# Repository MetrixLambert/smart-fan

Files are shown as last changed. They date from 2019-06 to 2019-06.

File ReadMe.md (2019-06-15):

# ReadMe

This repo contains all files used in my project **pulse** and **smart fan**

对各个文件夹的说明如下：

| folder | folder function |
| --- | --- |
| **0-report** | 两篇论文和作业说明 |
| **1-sim** | 所有的原理图和仿真文件 |
| **2-experiment** | **smart fan** 最终视频 |
| **3-code** | **smart fan** 使用代码 |
| **4-datasheet**  | 所使用芯片的 datasheet |
| **5-PCB** | 最终绘制的PCB文件 |

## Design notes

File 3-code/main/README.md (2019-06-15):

# ReadMe

this is the main program for smart fan 

first need to load LiquidCrystal_I2C module in Arduino 

if not use vscode like me , you can delete "./vscode" folder 

-- from lgr (Ethan)

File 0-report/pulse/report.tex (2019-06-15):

\documentclass{article}
 
\usepackage[margin=1in]{geometry}
\usepackage[strict]{changepage}
\usepackage{float}
\usepackage{fancyhdr}
\usepackage{mhchem}
\usepackage{siunitx}
\usepackage{wrapfig, booktabs}
\usepackage{enumitem}
\usepackage{ctex}
\usepackage{graphicx}
\usepackage{amsmath}
\usepackage{amssymb}
\usepackage{subfigure}
\usepackage{multirow}
\usepackage{multicol}
\usepackage{wrapfig}
\usepackage{indentfirst}
\usepackage[utf8]{inputenc}
\usepackage{geometry}
\usepackage{setspace}   %set space between lines
\usepackage{graphicx} %insert figure 
\usepackage{float} %设置图片浮动位置的宏包
\usepackage{subfigure} %插入多图时用子图显示的宏包
\usepackage{listings}   %插入代码的宏包
\usepackage{xcolor} % to define color 
\usepackage{verbatim}   %for comment 
\usepackage[breaklinks,colorlinks,linkcolor=black,citecolor=black,urlcolor=black]{hyperref} %for bookmark 

\setlength{\parindent}{2em}

\definecolor{mygray}{rgb}{0.5,0.5,0.5}  %totally used in code display
\definecolor{mygreen}{rgb}{0,0.6,0}

\lstset{                %代码显示格式设置
    numbers=left,                                   
    % where to put the line-numbers; possible values are (none, left, right)
    numberstyle=  \color{mygray}, 
    % the style that is used for the line-numbers
    keywordstyle= \color{ blue!70},
    basicstyle=\footnotesize,        
    % the size of the fonts that are used for the code
    commentstyle=\color{mygreen},    
    % comment style
    frame=single,	                   
    % adds a frame around the code, you can use frame=shadowboxs
    % with a rulesepcolor= \color{ red!20!green!20!blue!20} ,
    escapeinside=``, % 英文分号中可写入中文
    xleftmargin=4em,xrightmargin=2em, aboveskip=1em,
    framexleftmargin=2em
} 

\begin{document}

\begin{spacing}{1.5}

    %title  page 
    \thispagestyle{empty}
    \begin{center}
~\\[6cm]\rule{\linewidth}{0.5mm} \\[6mm]
{\Large 综合论文  \\  \textbf{{\LARGE 心率传感电路}}  \\[6mm]}
\rule{\linewidth}{0.5mm} \\[2cm]
{\Large 姓 名: 吕光冉}\\[.3cm]
{\Large 班 级:   自73 }\\[.3cm]
{\Large 学 号:  2017011574}\\[.3cm]
{\Large 日 期：\today }\\[.3cm]
    \end{center}

    \clearpage
    \phantom{s}

    %if need to make table of contents in pdf, below command is okay
\tableofcontents
\newpage

    \subsection{摘要}

    本文介绍了一个基于光电测量法的心率测量电路的设计与实现。
    本电路设计以MK986脉搏心率传感器检测所得波形为输入信号，
    经过运放滤波和信号放大后，通过一个施密特比较器输出处理后的脉搏信号。
    同时，为了增强电路的可靠性，在面包板上搭建电路并验证工作状态无误后，
    我最终绘制了一块PCB板。在实验检测后。成功得到了比较理想的，符合数字
    电平的脉搏信号。

    \textbf{关键词} ：心率测量电路，光电测量法，模拟电路设计

\section{引言——小米手环心率测量电路}

   我所选择的第一个综合论文题目为心率测量电路的设计与制作。

   之所以会选择这个题目，起源是我平时的一个小发现。
   有一次我在没有佩戴小米手环3的情况下，开启了其心率测量功能。结果我惊奇的发现，
   这时的小米手环测出了一个70多的数值。而当我再一次启动手环的测量功能后，
   我发现它竟然测出了180多的数值！
   
   对于我观察到的现象，一方面，我认为作为一款已经迈入市场的消费级电子产品，
   小米手环不应该在没人佩戴的前提下仍然能够测量到脉搏，这在我看来属于是产品设计缺陷。
   其次我认为，在所测量环境基本没有什么变化的时候，小米手环前后两次测量不应该有这么大
   差距。对这两个问题的好奇促使我去研究智能手环中心率测量电路的基本工作原理。
    
   经过调查发现，现在市面上存在的心率测量电路中，
   常见的测量原理有两种，一种是心动电流测量法，还有一种是光电透射（反射）测量法。

   第一种是心动电流测量法，需要使用到无线心率胸带。人体每次心脏跳动时，都会在胸口产生微弱的心动电流，
   而利用带有电极的无线心率胸带，就可以采集分析这样的电流，来对心率进行计数。
   这种测量方法的优点是测量十分精确，并且可以在运动过程中持续测量。但缺点在于其佩戴方式
   比较特殊，所以并不适用于普通消费者，而更适用于一些运动员。

   第二种是光电透射（或反射）测量法，这种测量方法也是智能手环测量心率的基本原理。
   光电透射测量法主要是利用了血液对光的吸收作用。由于在人体中，非血液成分对于光的吸
   收量基本是恒定的，而在血液中，静脉血的吸收波动相比于动脉血的吸收波动又十分微弱，可以忽略不计。
   所以，可以在恒定波长的光源照射下，通过监测“光的吸收率”这一模拟量的变化，并经过一定的滤波和计算后，
   就可以得到人体动脉血的跳动波形，从而获得心率跳动波形。

    其中，基于光电测量法的光电脉搏传感器通常又分成利用透射式和反射式两种。透射式的传感器
    其发射光源和光敏接收器件位于人体两侧，检测的是透射光光强变化，
    而反射式的传感器其光源和光敏器件位于同一侧，接收的是血液漫射和反射的光。
    由于智能手环本身的佩戴方式，其使用的是反射式的传感器。

   而本设计的设计目的为设计一个基于反射式光电透射原理的心率测量电路，最终要输出一个满足数字电平的
   脉搏信号，使得输出波形可以被后续 MCU 电路测量并进行数字处理。

\section{实现方案}

    我的心率测量电路设计方案如图\ref{fig:design_flow}所示：
    \begin{figure}[H]
        \centering
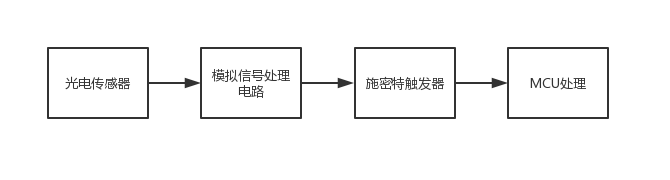
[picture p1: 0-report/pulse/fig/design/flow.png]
        
        \caption{整体设计方案}
        \label{fig:design_flow}
    \end{figure}
    
    在本设计中，光电传感器负责将血液跳动的光信号转化为微弱的电信号，然后经过模拟信号处理电路进行信号放大，噪声抑制以后，
    由施密特触发电路将模拟信号转化为可以由MCU处理的数字信号。

\section{电路原理分析}

    经过测量得知，第一级光电测量电路输出信号大致为一个有直流偏移的，变化幅值大致在100mV左右的脉搏波形。
    其中，直流电压会随着测量时间和接触的皮肤位置不同而变化，而脉搏波形的变化幅值也会因为传感器与皮肤接触的位置不同
    而变化。同时，传感器的输出电阻很小。    

    根据第一级光电传感器输出波形的以上特点，我设计的模拟信号处理电路原理图如图\ref{fig:design1}所示：

    \begin{figure}[H]
        \centering
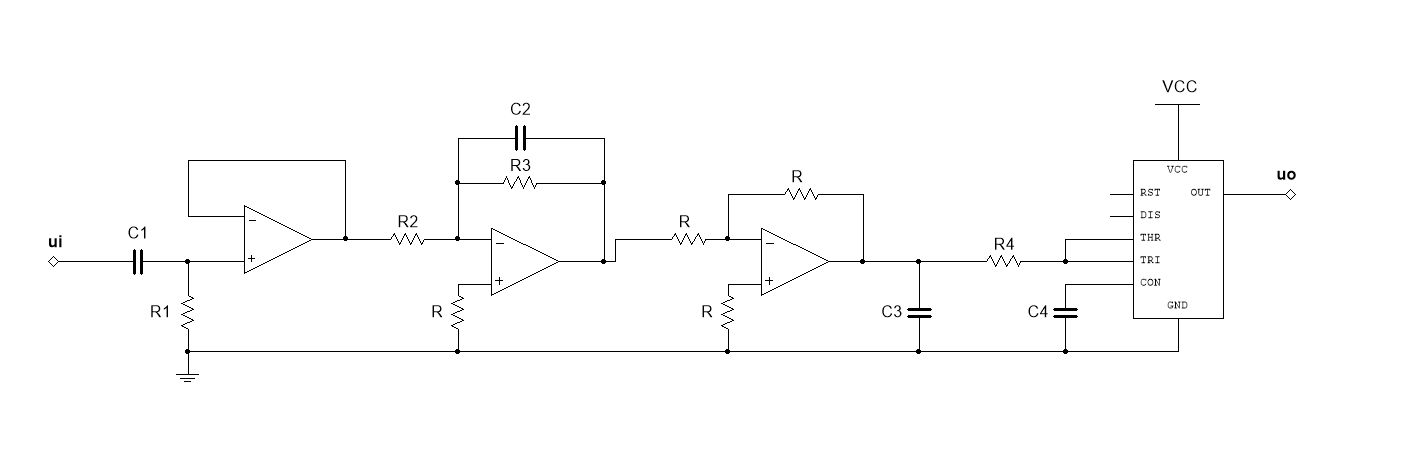
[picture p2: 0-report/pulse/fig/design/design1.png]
        
        \caption{模拟信号处理电路}
        \label{fig:design1}
    \end{figure}

    其中，第一级电路能隔离输入波形中的直流分量，并增大电路的输入电阻至$R_1$，
    第二级电路是一个微分器（相当于一个高通滤波器），并能够进行信号放大并进一步滤去低频噪声，
    第三级电路为低通RC电路和反相器，可以滤去输出级的高频噪声并将波形反向，
    最后一级电路为施密特触发器，可以将放大后的脉搏信号转变符合数字信号电平要求的脉搏信号。

    其中，对于中频段信号，模拟信号处理电路的输入输出电平之间的数学关系式为：
    \begin{equation}
        u_o = - \frac{R_3}{R_2} u_i
    \end{equation}

    通过表达式可知，在调试电路时，可以通过改变$\frac{R_3}{R_2}$ 来调整电路的放大倍数。

    而该电路的截止频率分别为：
    \begin{equation}
        \begin{cases}
            f_l = \frac{1}{2 \pi R_1 C_1}\\
            f_h \approx min \{ \frac{1}{2 \pi R_3 C_2}, \frac{1}{2 \pi R_1 C_1} \}
        \end{cases}
    \end{equation}

    所以可以通过调整 R1,C1,R3等参数来调整电路的幅频特性。

\section{整体电路仿真结果}

    我使用的仿真电路如图\ref{fig:sim1}所示。

    \begin{figure}[H]
        \centering
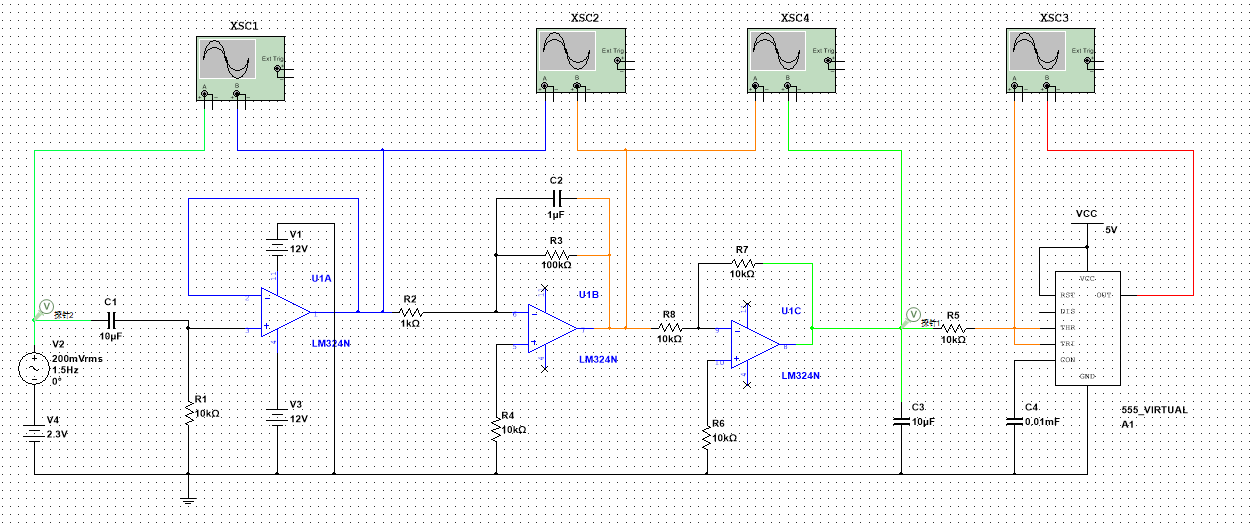
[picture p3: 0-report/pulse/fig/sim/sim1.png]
        
        \caption{心率测量电路仿真电路图}
        \label{fig:sim1}
    \end{figure}

    这里我用了一个直流电源和交流电源的叠加来模拟实际传感器输入信号。

    第一级电路的输入输出波形如图\ref{fig:sim1_result1}所示：
    \begin{figure}[H]
        \centering
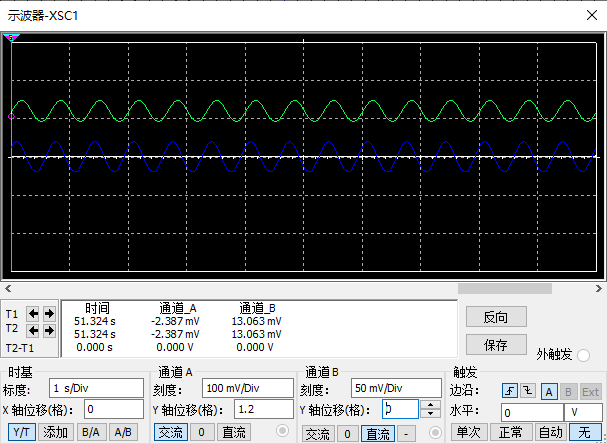
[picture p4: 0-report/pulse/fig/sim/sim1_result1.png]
        
        \caption{第一级电路传输特性}
        \label{fig:sim1_result1}
    \end{figure}
    
    从波形中可以看出，尽管有一定的相移，但是第一级电路已经成功滤去直流分量。

    第二级电路的电压传输特性如图\ref{fig:sim1_result2}所示：
    \begin{figure}[H]
        \centering
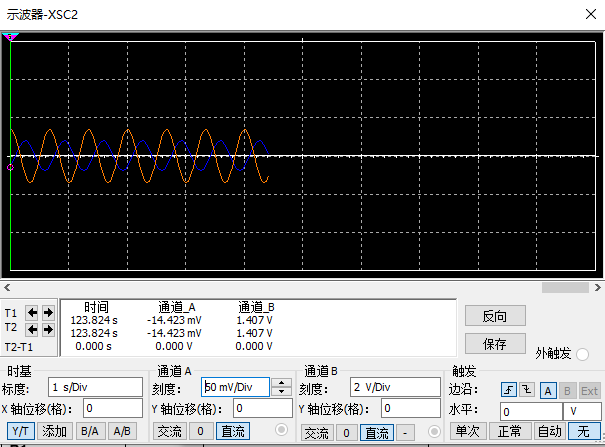
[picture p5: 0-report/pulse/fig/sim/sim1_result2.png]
        
        \caption{第二级电路传输特性}
        \label{fig:sim1_result2}
    \end{figure}
    
    此时，交流信号已经被成功放大。

    在经过低通滤波电路以后，施密特触发器的输入输出波形如图\ref{fig:sim1_result3}所示：
    \begin{figure}[H]
        \centering
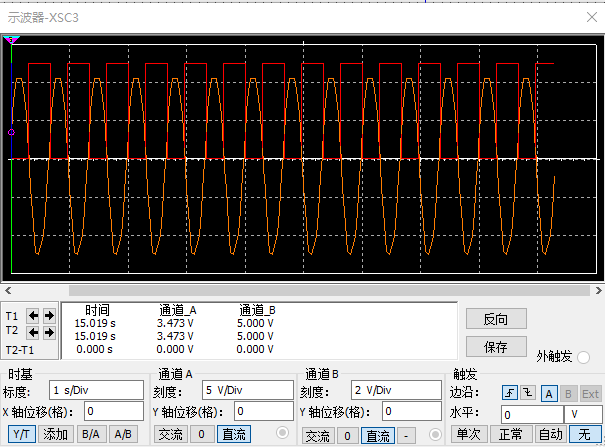
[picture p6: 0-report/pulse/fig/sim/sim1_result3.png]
        
        \caption{施密特电路输入输出波形}
        \label{fig:sim1_result3}
    \end{figure}
    
    可见，此时电路已经能够输出可以被MCU识别的数字信号。

    而对于模拟信号处理电路的幅频特性，仿真结果如图\ref{fig:sim1_result4}所示：
    \begin{figure}[H]
        \centering
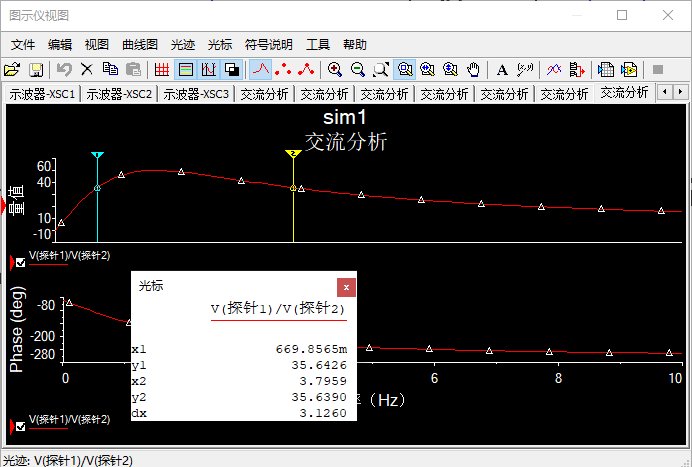
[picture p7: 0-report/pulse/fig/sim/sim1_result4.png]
        
        \caption{电路幅频特性}
        \label{fig:sim1_result4}
    \end{figure}

    可见，电路的低频截止频率为0.6Hz，高频截止频率为3.8Hz。这说明对于一般在1-3Hz的心跳信号，所设计的电路可以有效抑制
    电路高低频噪声并放大有效信号。

\section{电路搭建与实测结果}

    在面包板上搭建完电路并确认电路可以正常工作后，我在李兆基科技大楼绘制并现场制作了一块PCB板。
    但由于李兆基大楼的技术所限，
    我最终制作的仅仅是一块单面PCB板。制作成果如图\ref{fig:PCB1},\ref{fig:PCB2}所示：

    \begin{figure}[H]
        \centering
        
        \caption{PCB板-未焊接}
        \label{fig:PCB1}
    \end{figure}

    \begin{figure}[H]
        \centering
        
        \caption{PCB板-已焊接}
        \label{fig:PCB2}
    \end{figure}
    
    由于在绘制PCB板时，电路封装出现了一些问题，所以最后多使用了一块LM324芯片。

    之后我用魔术胶带将传感器绑在我的手腕上开始测量，如图\ref{fig:pulse1}所示：
    \begin{figure}[H]
        \centering
        
        \caption{传感器绑定方式}
        \label{fig:pulse1}
    \end{figure}
    
    此时，传感器输出波形如图\ref{fig:result1}所示：
    \begin{figure}[H]
        \centering
        
        \caption{传感器输出波形}
        \label{fig:result1}
    \end{figure}

    可见，此时传感器的输出波形中，存在一个2V以上的直流量。而有效的脉搏信号幅值大约有300mV，并且信号中存在
    高频噪声和中频（与脉搏信号频率相近的）噪声。
    
    第一级电路输出波形如图\ref{fig:result2}所示：
    \begin{figure}[H]
        \centering
        
        \caption{第一级电路输出波形}
        \label{fig:result2}
    \end{figure}

    从输出波形可以看出，此时第一级电路已经成功滤去输入信号的直流分量。
    但同时，有效信号的幅值也被减少至200mV左右。

    第二级电路输出波形如图\ref{fig:result3}所示：
    \begin{figure}[H]
        \centering
        
        \caption{第二级电路输出波形}
        \label{fig:result3}
    \end{figure}

    我在实际电路焊接时，我选择使用了一个100k可调电阻来代替仿真电路中的
    $R_3$ 电阻，这样就可以根据输入信号幅值的不同来手动调整电路放大倍数。
    
    如图\ref{fig:result3}所示的输出波形为调整放大倍数后的波形，
    可以看出，此时电路中与脉搏信号频率相近的干扰信号幅值不到1V，在反向后是无法触发施密特触发器的。
    这样一来就可以通过施密特触发器来过滤掉与脉搏信号频率相近的噪声。
    
    同时也可以观察到，在未进行高次噪声滤波前，电路中还是存在很强的高次噪声的。
    这样的噪声可以被后一级低通滤波器和施密特触发器抑制。但这也说明在下一版改进电路中，
    应该在前几级引入低通滤波器来提前抑制高频噪声。
    
    最后级电路输出波形如图\ref{fig:result4}所示：
    \begin{figure}[H]
        \centering
        
        \caption{第三级电路输出波形}
        \label{fig:result4}
    \end{figure}

    可以看出，这时电路已经获得了十分理想的，满足数字电平的脉搏波形。
    （这里的波形在第一次测量时忘记保存，图\ref{fig:result4}为后来补测的结果）。    

\section{实验中电路出现的问题以及原因分析}

    相对于我的第二个项目“智能风扇”，这个项目要简单许多。在制作过程中，我遇到的主要问题包括以下几点：

    \begin{enumerate}
        \item 忽略输出信号正负极性的问题
        
        为了在最后一级仅仅检测正极性信号，我才在最后一级选用了由555构成的施密特触发电路（不需要引入额外的参考电压），而不是
        使用在模电实验中我们通常使用的稳压管滞回比较器（需要引入额外的参考电压才能仅仅检测正电压）。 

        但是在第一次在面包板上搭建电路时，我忽略了第二级电路输出有反向的效果，这导致了原本想要检测的最为明显的
        正脉搏信号变成了负信号，无法被施密特触发器识别。

        这个问题在多引入了一个反相器后，得到了完美的解决。这也提醒我在电路设计时应该关注信号的极性问题。

        \item PCB绘制没有引出测试点
        
        由于是自己初次绘制PCB，没有足够的PCB绘制经验，所以在最终的电路中，PCB上引出的引脚
        只有各类电源和输入输出信号的引脚。
        这导致了在测试PCB电路工作状态时，由于焊接的元件引脚和示波器探头接触面积过小，
        探头上检测到的信号十分不稳定。
        
        所以说在PCB绘制时，应该事先考虑到测试的需要，在PCB板上引出合适的测试点以方便测试。

        \item 电源种类过多

        和我的第二个项目“智能风扇”相同的是，这个电路同样存在电源种类过多的问题。而电源种类过多一方面会增加电源管理模块
        设计的复杂度，另一方面会增大电路功耗，对于一款消费级电子产品是很不合适的。

        而根据所设计电路的实际工作状态，由于所处理的信号为变化的信号，所以电路是存在被改为单电源电路的可能性的。
        
        我初步设计的单电源脉搏检测电路如图\ref{fig:design2}所示：

        \begin{figure}[H]
            \centering
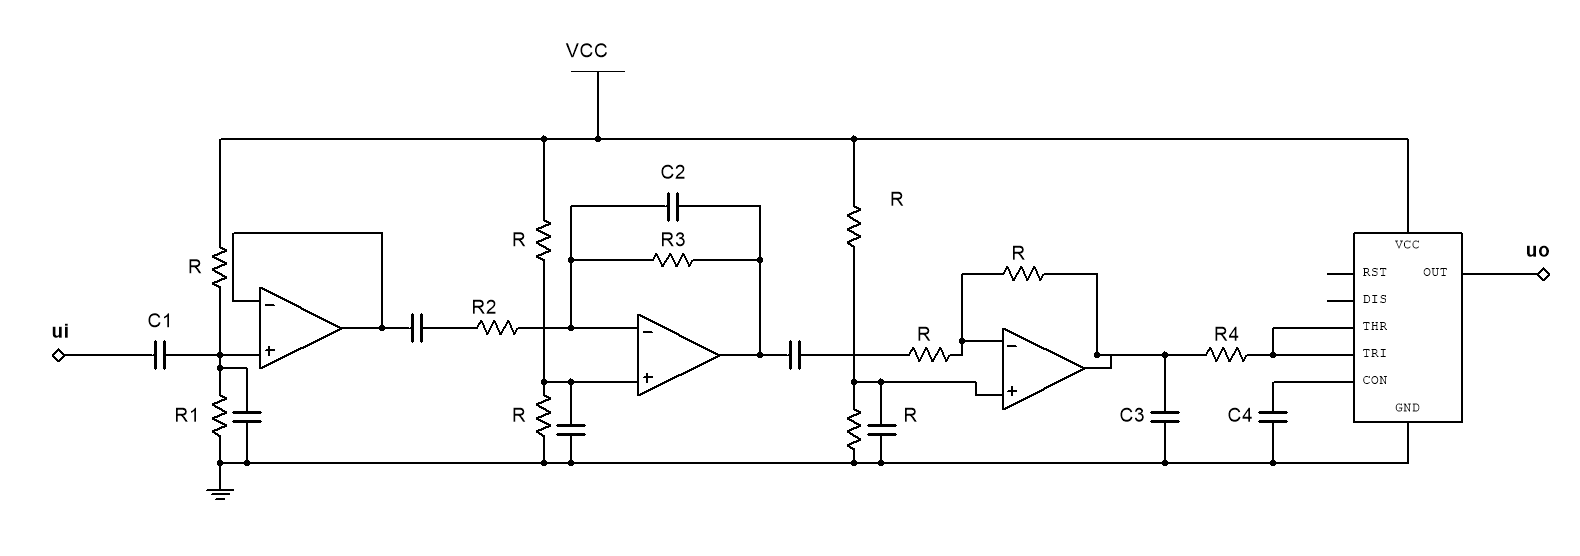
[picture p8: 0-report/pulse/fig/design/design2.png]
            
            \caption{第二版心率测量电路}
            \label{fig:design2}
        \end{figure}
        
        该设计中所有的LM324所接正电压为5V，负电压为0V。其中：
        \begin{enumerate}
            \item $R$ 和 $R_1$负责给运放提供2.5V的参考电位。
            \item $R_1$ 和 $C_1$ 构成高通滤波器，负责隔离电平直流量
            \item 第一级运放为跟随器，负责增大电路的输入电阻
            \item 跟随器后的电容起到进一步隔离直流分量的作用。
            \item R2,R3,C2和第二个运放构成反向微分器（相当于高通滤波器），同时起到放大信号的作用
            \item 第二级运放仍然设置其正极参考电位为2.5V
            \item 第三级运放为一个反相器，其基准电平仍然为2.5V
            \item R4,C3构成低通滤波器，负责过滤高频噪声。
            \item 最后一级由555构成施密特触发器，负责转化波形脉搏波形为数字信号波形。
        \end{enumerate}

        但是由于时间关系，我并没能完成这一版电路的仿真、实验和PCB绘制。这也是本项目的一个遗憾。

    \end{enumerate}

\section{项目的改进方向}

    项目的主要改进方向包括如下几点：

    \begin{enumerate}
        \item 提升传感器的稳定性。在实验时我发现，现在使用的脉搏测量模块工作状态并不完全稳定，其输出会因传感器所接触的皮肤位置不同
        而产生明显变化，
        以致于略微移动一下传感器的位置，就会出现脉搏信号检测不到的问题。
        所以在后续电路改进时，应该首先考虑更换传感器来提升电路工作的稳定性。

        \item 减少电源数量。在最终搭建的电路中，所使用的电源种类过多，包括有正负12V，正5V三种电源。一方面，种类过多给
        电路的搭建和调试带来很大的不便，另一方面，如果该心率传感电路要被融入到消费类电子产品中，减少电源数量可以
        有效的降低因电平转换而消耗的功率，从而提升便携式电子设备的电路工作时间。

        \item 在前几级电路中引入一定的低通滤波器以滤出高频噪声。在实际测量过程中，我发现电路中存在很多的高频噪声，这
        一点在第一版电路设计的时候是没有考虑到的。

    \end{enumerate}

\end{spacing}
\end{document}

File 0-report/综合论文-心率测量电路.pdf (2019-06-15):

## 综合论文

# 心率传感电路

## 姓名: 吕光冉

## 班级: 自 73

学号: 2017011574

## 日期：2019 年 6 月 15 日

目录

1 引言——小米手环心率测量电路 | 3
2 实现方案 | 4
3 电路原理分析 | 4
4 整体电路仿真结果 | 5
5 电路搭建与实测结果 | 6
6 实验中电路出现的问题以及原因分析 | 10
7 项目的改进方向 | 11

### 0.1 摘要

本文介绍了一个基于光电测量法的心率测量电路的设计与实现。本电路设计以 MK986 脉搏心率传

感器检测所得波形为输入信号，经过运放滤波和信号放大后，通过一个施密特比较器输出处理后的脉搏

信号。同时，为了增强电路的可靠性，在面包板上搭建电路并验证工作状态无误后，我最终绘制了一块

PCB 板。在实验检测后。成功得到了比较理想的，符合数字电平的脉搏信号。

关键词：心率测量电路，光电测量法，模拟电路设计

## 1 引言——小米手环心率测量电路

我所选择的第一个综合论文题目为心率测量电路的设计与制作。

之所以会选择这个题目，起源是我平时的一个小发现。有一次我在没有佩戴小米手环 3 的情况下，

开启了其心率测量功能。结果我惊奇的发现，这时的小米手环测出了一个 70 多的数值。而当我再一次

启动手环的测量功能后，我发现它竟然测出了 180 多的数值！

对于我观察到的现象，一方面，我认为作为一款已经迈入市场的消费级电子产品，小米手环不应该

在没人佩戴的前提下仍然能够测量到脉搏，这在我看来属于是产品设计缺陷。其次我认为，在所测量环

境基本没有什么变化的时候，小米手环前后两次测量不应该有这么大差距。对这两个问题的好奇促使

我去研究智能手环中心率测量电路的基本工作原理。

经过调查发现，现在市面上存在的心率测量电路中，常见的测量原理有两种，一种是心动电流测量

法，还有一种是光电透射（反射）测量法。

第一种是心动电流测量法，需要使用到无线心率胸带。人体每次心脏跳动时，都会在胸口产生微弱

的心动电流，而利用带有电极的无线心率胸带，就可以采集分析这样的电流，来对心率进行计数。这种

测量方法的优点是测量十分精确，并且可以在运动过程中持续测量。但缺点在于其佩戴方式比较特殊，

所以并不适用于普通消费者，而更适用于一些运动员。

第二种是光电透射（或反射）测量法，这种测量方法也是智能手环测量心率的基本原理。光电透射

测量法主要是利用了血液对光的吸收作用。由于在人体中，非血液成分对于光的吸收量基本是恒定的，

而在血液中，静脉血的吸收波动相比于动脉血的吸收波动又十分微弱，可以忽略不计。所以，可以在恒

定波长的光源照射下，通过监测“光的吸收率”这一模拟量的变化，并经过一定的滤波和计算后，就可

以得到人体动脉血的跳动波形，从而获得心率跳动波形。

其中，基于光电测量法的光电脉搏传感器通常又分成利用透射式和反射式两种。透射式的传感器其

发射光源和光敏接收器件位于人体两侧，检测的是透射光光强变化，而反射式的传感器其光源和光敏器

件位于同一侧，接收的是血液漫射和反射的光。由于智能手环本身的佩戴方式，其使用的是反射式的传

感器。

而本设计的设计目的为设计一个基于反射式光电透射原理的心率测量电路，最终要输出一个满足

数字电平的脉搏信号，使得输出波形可以被后续 MCU 电路测量并进行数字处理。

## 2 实现方案

我的心率测量电路设计方案如图1所示：

图 1: 整体设计方案

在本设计中，光电传感器负责将血液跳动的光信号转化为微弱的电信号，然后经过模拟信号处理电

路进行信号放大，噪声抑制以后，由施密特触发电路将模拟信号转化为可以由 MCU 处理的数字信号。

## 3 电路原理分析

经过测量得知，第一级光电测量电路输出信号大致为一个有直流偏移的，变化幅值大致在 100mV

左右的脉搏波形。其中，直流电压会随着测量时间和接触的皮肤位置不同而变化，而脉搏波形的变化幅

值也会因为传感器与皮肤接触的位置不同而变化。同时，传感器的输出电阻很小。

根据第一级光电传感器输出波形的以上特点，我设计的模拟信号处理电路原理图如图2所示：


图 2: 模拟信号处理电路

其中，第一级电路能隔离输入波形中的直流分量，并增大电路的输入电阻至 R1，第二级电路是一

个微分器（相当于一个高通滤波器），并能够进行信号放大并进一步滤去低频噪声，第三级电路为低通

RC 电路和反相器，可以滤去输出级的高频噪声并将波形反向，最后一级电路为施密特触发器，可以将

放大后的脉搏信号转变符合数字信号电平要求的脉搏信号。

其中，对于中频段信号，模拟信号处理电路的输入输出电平之间的数学关系式为：

uo = −

R3
R2
ui | (1)

通过表达式可知，在调试电路时，可以通过改变 R3
R2 来调整电路的放大倍数。

而该电路的截止频率分别为：

fl =

1
2πR1C1
fh ≈ min{

1
2πR3C2

,

1
2πR1C1

}

(2)

所以可以通过调整 R1,C1,R3 等参数来调整电路的幅频特性。

## 4 整体电路仿真结果

我使用的仿真电路如图3所示。


图 3: 心率测量电路仿真电路图

这里我用了一个直流电源和交流电源的叠加来模拟实际传感器输入信号。

第一级电路的输入输出波形如图4所示：

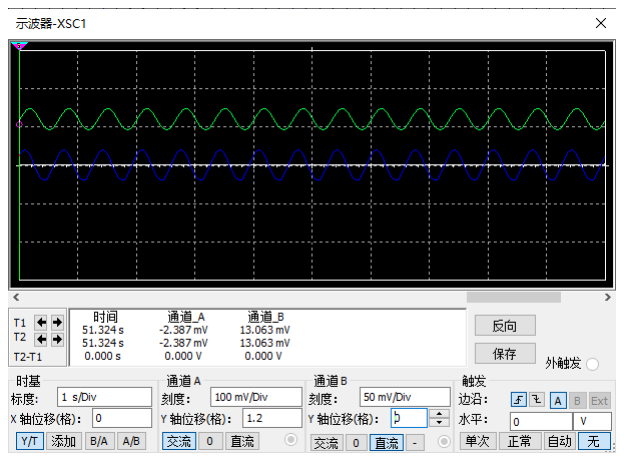
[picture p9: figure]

图 4: 第一级电路传输特性

从波形中可以看出，尽管有一定的相移，但是第一级电路已经成功滤去直流分量。

第二级电路的电压传输特性如图5所示：


图 5: 第二级电路传输特性

此时，交流信号已经被成功放大。

在经过低通滤波电路以后，施密特触发器的输入输出波形如图6所示：


图 6: 施密特电路输入输出波形

可见，此时电路已经能够输出可以被 MCU 识别的数字信号。

而对于模拟信号处理电路的幅频特性，仿真结果如图7所示：

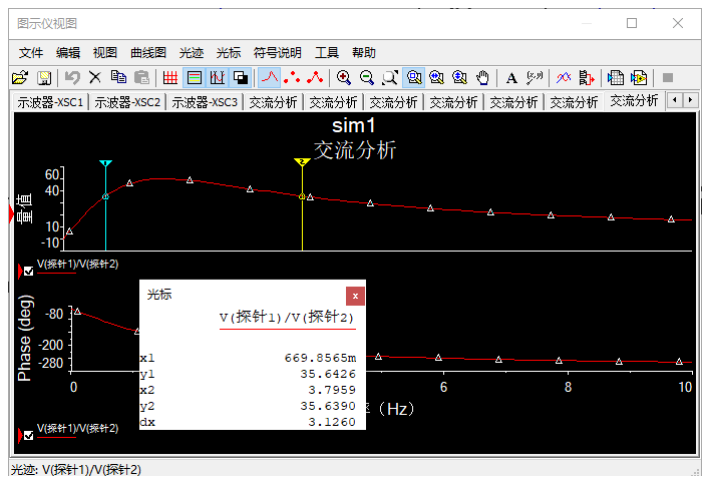
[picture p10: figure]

图 7: 电路幅频特性

可见，电路的低频截止频率为 0.6Hz，高频截止频率为 3.8Hz。这说明对于一般在 1-3Hz 的心跳信

号，所设计的电路可以有效抑制电路高低频噪声并放大有效信号。

## 5 电路搭建与实测结果

在面包板上搭建完电路并确认电路可以正常工作后，我在李兆基科技大楼绘制并现场制作了一块

PCB 板。但由于李兆基大楼的技术所限，我最终制作的仅仅是一块单面 PCB 板。制作成果如图8,9所

示：

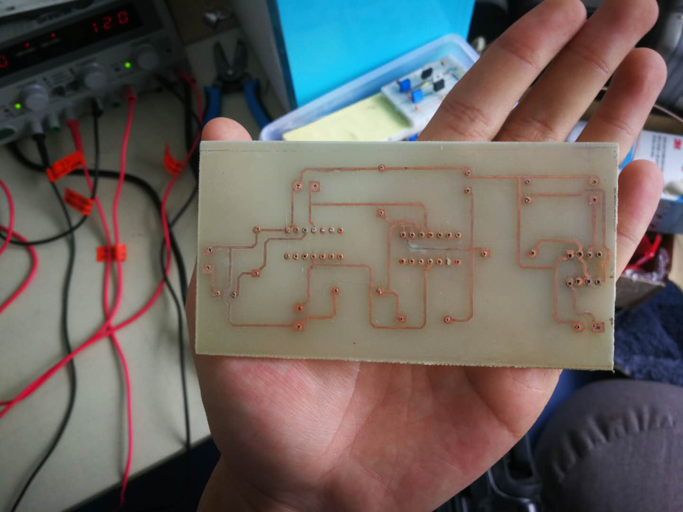
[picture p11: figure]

图 8: PCB 板-未焊接

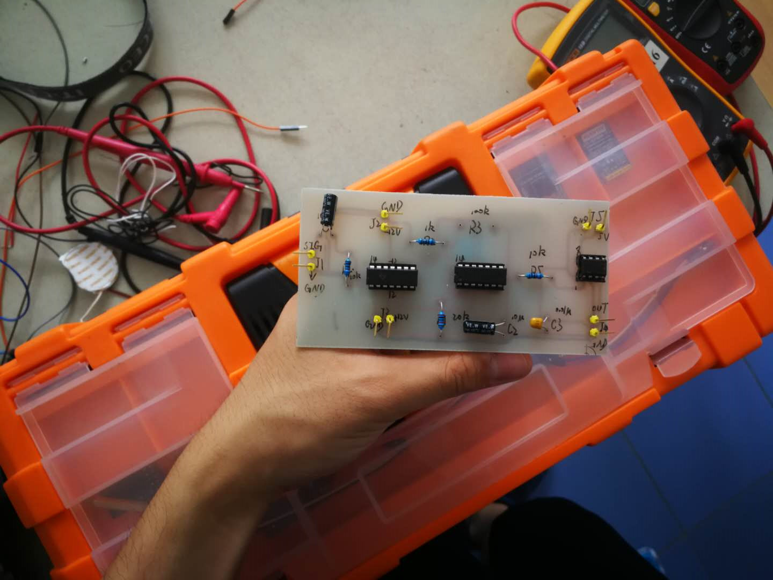
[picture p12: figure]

图 9: PCB 板-已焊接

由于在绘制 PCB 板时，电路封装出现了一些问题，所以最后多使用了一块 LM324 芯片。

之后我用魔术胶带将传感器绑在我的手腕上开始测量，如图10所示：

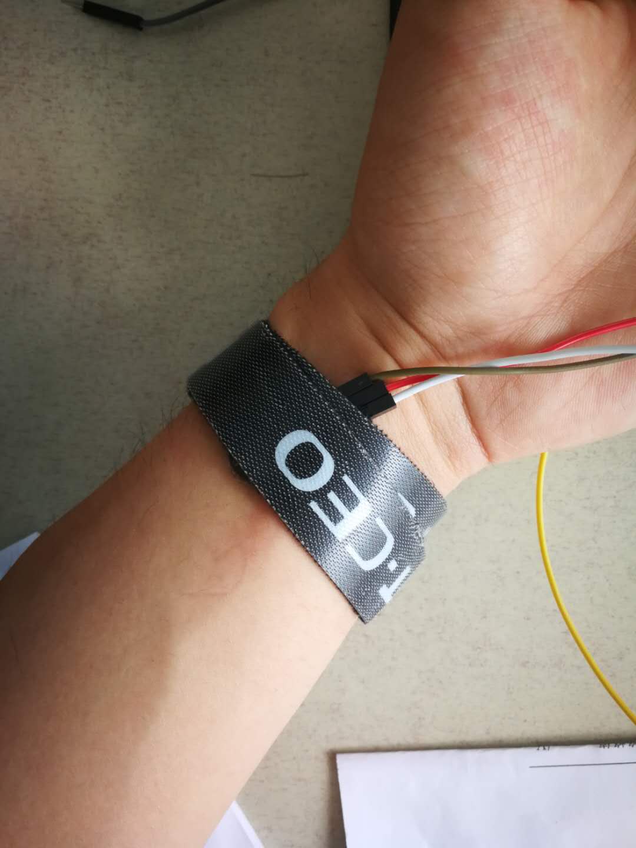
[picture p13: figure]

图 10: 传感器绑定方式

此时，传感器输出波形如图11所示：

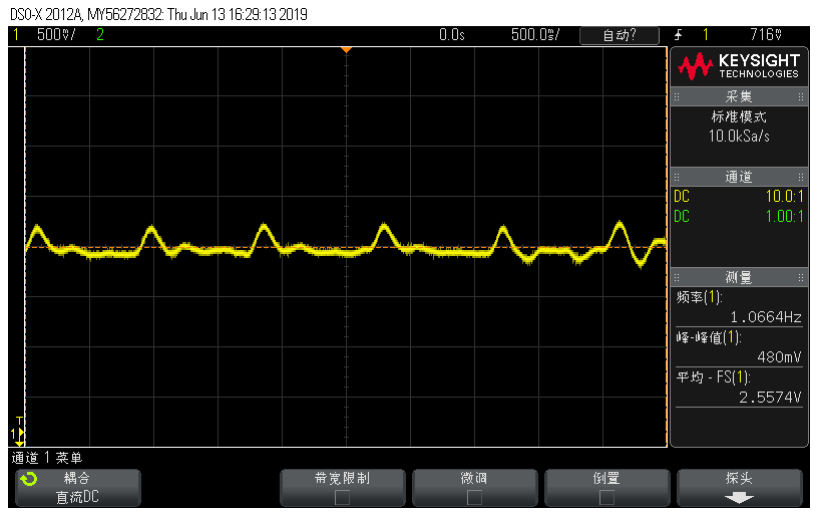
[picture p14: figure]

图 11: 传感器输出波形

可见，此时传感器的输出波形中，存在一个 2V 以上的直流量。而有效的脉搏信号幅值大约有 300mV，

并且信号中存在高频噪声和中频（与脉搏信号频率相近的）噪声。

第一级电路输出波形如图12所示：

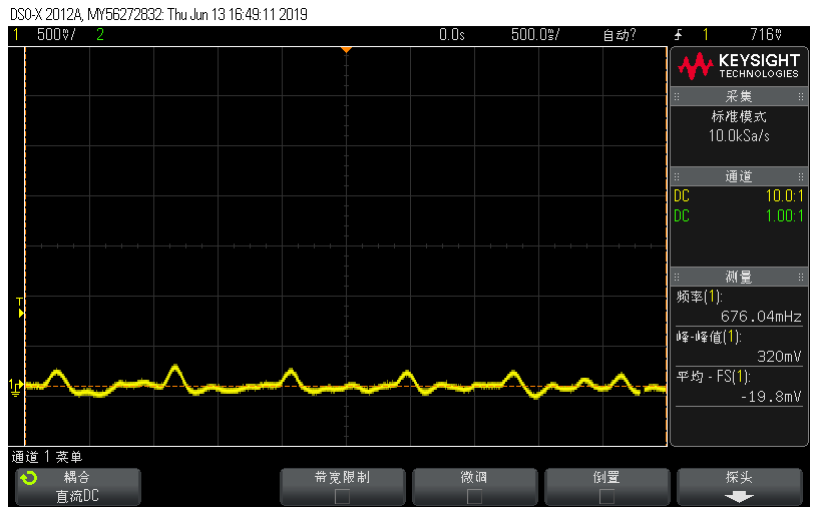
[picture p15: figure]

图 12: 第一级电路输出波形

从输出波形可以看出，此时第一级电路已经成功滤去输入信号的直流分量。但同时，有效信号的幅

值也被减少至 200mV 左右。

第二级电路输出波形如图13所示：

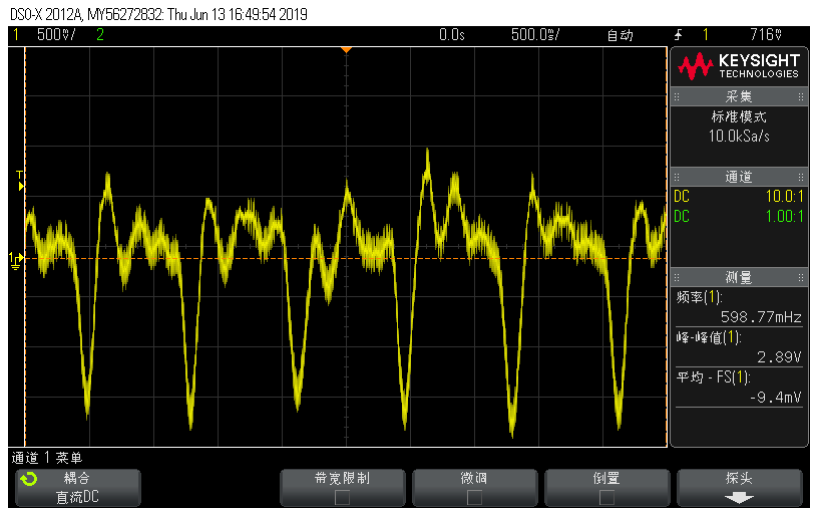
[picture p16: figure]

图 13: 第二级电路输出波形

我在实际电路焊接时，我选择使用了一个 100k 可调电阻来代替仿真电路中的 R3 电阻，这样就可

以根据输入信号幅值的不同来手动调整电路放大倍数。

如图13所示的输出波形为调整放大倍数后的波形，可以看出，此时电路中与脉搏信号频率相近的干

扰信号幅值不到 1V，在反向后是无法触发施密特触发器的。这样一来就可以通过施密特触发器来过滤

掉与脉搏信号频率相近的噪声。

同时也可以观察到，在未进行高次噪声滤波前，电路中还是存在很强的高次噪声的。这样的噪声可

以被后一级低通滤波器和施密特触发器抑制。但这也说明在下一版改进电路中，应该在前几级引入低

通滤波器来提前抑制高频噪声。

最后级电路输出波形如图14所示：

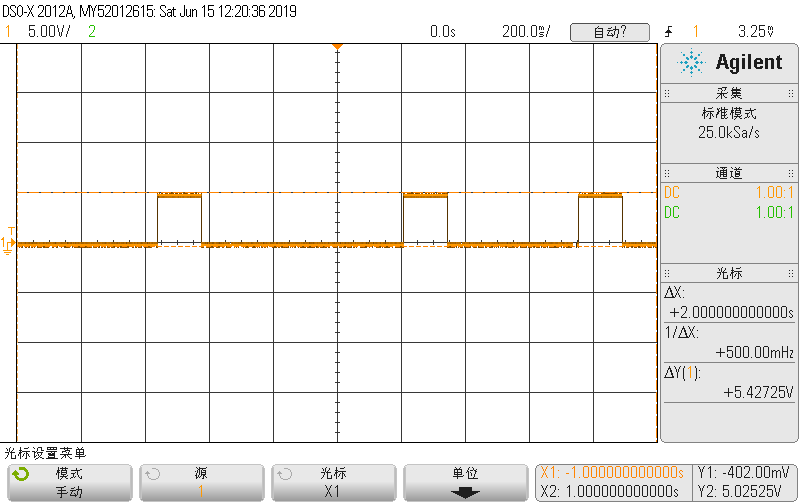
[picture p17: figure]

图 14: 第三级电路输出波形

可以看出，这时电路已经获得了十分理想的，满足数字电平的脉搏波形。（这里的波形在第一次测

量时忘记保存，图14为后来补测的结果）。

## 6 实验中电路出现的问题以及原因分析

相对于我的第二个项目“智能风扇”，这个项目要简单许多。在制作过程中，我遇到的主要问题包

括以下几点：

1. 忽略输出信号正负极性的问题

为了在最后一级仅仅检测正极性信号，我才在最后一级选用了由 555 构成的施密特触发电路（不

需要引入额外的参考电压），而不是使用在模电实验中我们通常使用的稳压管滞回比较器（需要引

入额外的参考电压才能仅仅检测正电压）。

但是在第一次在面包板上搭建电路时，我忽略了第二级电路输出有反向的效果，这导致了原本想

要检测的最为明显的正脉搏信号变成了负信号，无法被施密特触发器识别。

这个问题在多引入了一个反相器后，得到了完美的解决。这也提醒我在电路设计时应该关注信号

的极性问题。

2. PCB 绘制没有引出测试点

由于是自己初次绘制 PCB，没有足够的 PCB 绘制经验，所以在最终的电路中，PCB 上引出的引

脚只有各类电源和输入输出信号的引脚。这导致了在测试 PCB 电路工作状态时，由于焊接的元

件引脚和示波器探头接触面积过小，探头上检测到的信号十分不稳定。

所以说在 PCB 绘制时，应该事先考虑到测试的需要，在 PCB 板上引出合适的测试点以方便测

试。

3. 电源种类过多

和我的第二个项目“智能风扇”相同的是，这个电路同样存在电源种类过多的问题。而电源种类

过多一方面会增加电源管理模块设计的复杂度，另一方面会增大电路功耗，对于一款消费级电子

产品是很不合适的。

而根据所设计电路的实际工作状态，由于所处理的信号为变化的信号，所以电路是存在被改为单

电源电路的可能性的。

我初步设计的单电源脉搏检测电路如图15所示：


图 15: 第二版心率测量电路

该设计中所有的 LM324 所接正电压为 5V，负电压为 0V。其中：

(a) R 和 R1 负责给运放提供 2.5V 的参考电位。
(b) R1 和 C1 构成高通滤波器，负责隔离电平直流量
(c) 第一级运放为跟随器，负责增大电路的输入电阻
(d) 跟随器后的电容起到进一步隔离直流分量的作用。
(e) R2,R3,C2 和第二个运放构成反向微分器（相当于高通滤波器），同时起到放大信号的作用
(f) 第二级运放仍然设置其正极参考电位为 2.5V
(g) 第三级运放为一个反相器，其基准电平仍然为 2.5V
(h) R4,C3 构成低通滤波器，负责过滤高频噪声。
(i) 最后一级由 555 构成施密特触发器，负责转化波形脉搏波形为数字信号波形。

但是由于时间关系，我并没能完成这一版电路的仿真、实验和 PCB 绘制。这也是本项目的一个

遗憾。

## 7 项目的改进方向

项目的主要改进方向包括如下几点：

1. 提升传感器的稳定性。在实验时我发现，现在使用的脉搏测量模块工作状态并不完全稳定，其输

出会因传感器所接触的皮肤位置不同而产生明显变化，以致于略微移动一下传感器的位置，就会

出现脉搏信号检测不到的问题。所以在后续电路改进时，应该首先考虑更换传感器来提升电路工

作的稳定性。

2. 减少电源数量。在最终搭建的电路中，所使用的电源种类过多，包括有正负 12V，正 5V 三种电

源。一方面，种类过多给电路的搭建和调试带来很大的不便，另一方面，如果该心率传感电路要

被融入到消费类电子产品中，减少电源数量可以有效的降低因电平转换而消耗的功率，从而提升

便携式电子设备的电路工作时间。

3. 在前几级电路中引入一定的低通滤波器以滤出高频噪声。在实际测量过程中，我发现电路中存在

很多的高频噪声，这一点在第一版电路设计的时候是没有考虑到的。

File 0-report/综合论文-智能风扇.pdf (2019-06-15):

## 综合论文

# 智能风扇

## 姓名: 吕光冉

## 班级: 自 73

学号: 2017011574

## 日期：2019 年 6 月 16 日

目录

1 引言 | 3
2 设计目标 | 3
3 实现方式 | 3
4 基本电路模块电路原理 | 5
5 模拟电路仿真结果 | 10
6 电路搭建与实测结果 | 20
7 实验中电路出现的问题以及原因分析 | 29
8 项目的改进方向 | 31

### 0.1 摘要

本文介绍了一个智能风扇系统的设计与实现。本设计以 Arduino Mega 为主控板，利用基于 PT1000

的灵敏温度测量电路感知环境温度，利用基于热释电传感探头 RE200B 的人体感知电路感知人是否在

检测范围内出现，利用这两个方面的环境信息来自动调整风扇转速。同时，为了实现风扇的可携带性，

本设计在电源管理模块中，使用了 5V 电压稳压可调节模块，正负电源模块和 DC/DC 升压斩波电路

等模块来配合 12V 锂电池来给电路提供电源。

关键词：智能风扇；小型电子系统设计；模拟电路；数字电路

## 1 引言

我所选择的第二个综合论文题目为智能风扇系统的设计与制作。

在炎炎夏日，一个好的可携带风扇对人们就变得十分重要。在我自己使用风扇的过程中，我发现市

面上所售卖的风扇主要存在以下两个问题：一方面，如果忘记关闭风扇电源，即使是在人已经离开房间

以后，它也不能自动关闭以节省电池电量，另一方面，大多数风扇都不具备测温功能，只能通过用户手

动根据体感温度调节风扇转速。

所以说，我想要自己设计并实现这样一款智能风扇：一，它首先要体积较小，使用电池供电，具有

可携带性；二，它要能够感知人体，在人离开风扇的检测距离以后，自动关闭风扇；三，它应该能够根

据环境温度，智能调节风扇转速；四，它最好能实现比较好的用户互动，有显示屏和蓝牙 APP 等方式

来接收用户指令。

## 2 设计目标

1. 使用电池供电，具有便携性
2. 能进行人体检测，在人离开检测范围后，关闭风扇
3. 能根据环境温度，智能调节风扇转速
4. 有显示屏显示当前工作状态
5. 能通过蓝牙进行连接，与用户手机 APP 进行连接后，由用户调节其在不同温度下的转速

## 3 实现方式

整个电子系统的实现框图如图1所示：

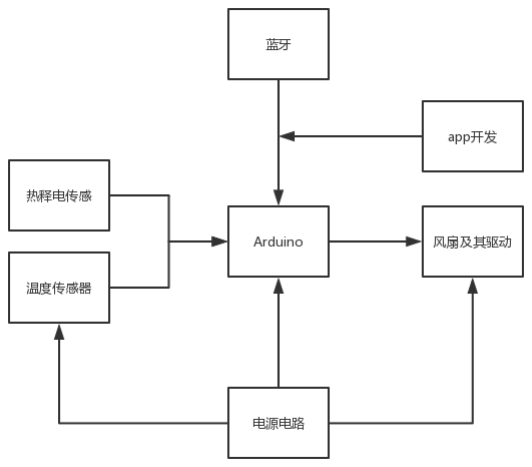
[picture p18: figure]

图 1: 整体电路实现框图

在这里，我将整个电子系统分为下列模块：主控板模块，温度传感器模块，热释电传感模块，风扇

及其驱动模块，蓝牙模块与对应的 APP，电源电路模块。

其中，热释电传感器是用来实现人体检测的功能，温度传感器负责检测环境温度，风扇及其驱动电

路负责驱动风扇运转，蓝牙及 APP 模块负责实现与用户的蓝牙连接，主控板 Arduino Mega 负责实现

数字控制逻辑，即获取热释电传感和温度传感器输出的环境信息，根据用户蓝牙设置的预定义功能，自

主决定风扇转速。并且，整个电路的供电问题，都由电源管理模块负责。

其中，根据传感器，主控板，风扇等模块所需要的电源类型，电源管理模块包括有：

图 2: 电源管理模块设计

而整个项目我的基本调试流程如下：

图 3: 基本调试流程

在下文中，我也将根据这一思路，阐述我的电路的设计过程，仿真结果以及实测结果。

## 4 基本电路模块电路原理

### 4.1 模拟电路模块

1. 5V 稳压电路

5V 稳压电路电路原理图：

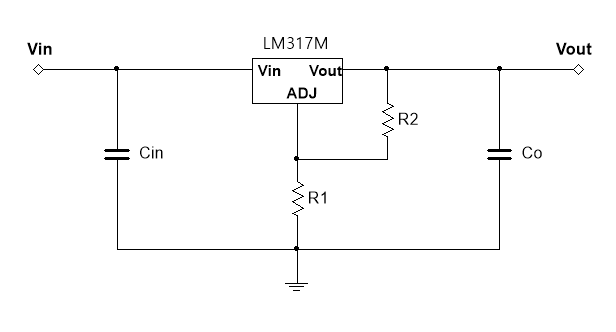
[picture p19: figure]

图 4: 5V 稳压电路原理图

我为了实现 5V 电压可以进行微调，使用了一个电压可调电路。其中，三端稳压器使用了 LM317M。

在输入电压足够大，公共端 ADJ 处电流可以近似忽略的条件下，电路输出电压满足关系：

Vout = 1.25(1 + R2
R1
)V | (1)

由于使用到了三端稳压器，其脉动系数 S 应该不会太大，可以满足后级电路需求。

2. 正负电源电路

我设计的正负电源电路原理图如图5所示：

图 5: 正负电源电路

在输入电压足够大，并且 COMMON 端电流可以被近似忽略时，电路输出近似满足下列关系：

Vout+ = 5(1 + R1
R2

)V

Vout− = −5(1 + R3
R4

)V

(2)

3. 温度测量电路

温度测量电路原理图如图6所示：

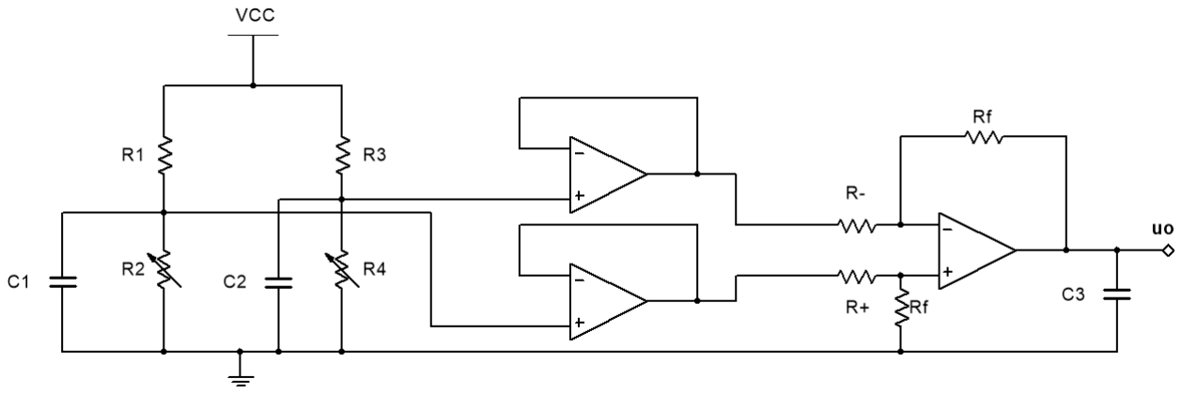
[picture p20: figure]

图 6: 温度测量电路原理图

温度测量电路的设计是基于铂电阻（PT1000）的温度特性。铂电阻在不同温度下的阻值不同且数

值比较固定，在将铂电阻阻值变化转变为电信号后，经过一定的运算电路就可以得到比较精确的

温度测量值。

在电路图中，R2 为 PT1000 铂电阻，其阻值随温度变化，R4 为调零电阻，可以调整电路使其在

0

◦C 时输出为 0。R1,R2,R3,R4 构成电桥电路。电桥电路的两个输出值在经过由精密运放构成的

跟随器之后，进入最后一级电路做差并被放大。原理图中 C1,C2 负责稳定输入电压，消除自激振

荡，C3 负责稳定输出电压，滤去高频噪声。

根据 PT1000 铂电阻的温度特性，在 0 摄氏度时，PT1000 电阻阻值为 1000 Ω，其后，每上升 1

摄氏度，其阻值大致上升 4 Ω. 则根据 R1，R2 分压关系，可知在 k 摄氏度时，如果假设 R1 足

够大，则电桥左路的输出电压为：

V+ =

R2
R2 + R1

VCC =

1000 + 4k
R1 + 1000 + 4k

VCC ≈

1000 + 4k
R1 + 1000
VCC | (3)

此时，若调节电路在 0 摄氏度时输出为 0，则电桥右路输出电压为：

V− =

R4
R3 + R4

VCC =

1000
1000 + R1
VCC | (4)

因此，在最后一级，当正极输入电阻和输出电阻阻值相等时，有：

Vout =

Rf
R+

(V+ − V−) ≈

Rf
R+

·

4k
R1 + 1000
VCC | (5)

通过最后一级的比例调整，将电压近似的转化为主控板可以直接读取的模拟电压值。

4. 热释电测量电路

热释电传感电路用于检测指定距离内是否有人存在。其基本测量原理是热释电基于热释电传感探

头（三极管）的三端特性。热释电传感探头可以将吸收到的红外辐射转化为微弱的电信号，而在

热释电探头上加上菲涅尔透镜则可以有效削弱环境干扰信号，保留人体热电信号，所以该传感探

头可以用于测量是否有人在其探测范围内。

但是经过测量，我发现，我们使用的被动式热释电传感探头实际上并不完全可靠。当有人进入探

头的探测范围（由于项目需要，我设定为 20cm）后，热释电传感探头输出电平是一个直流分量和

近似为 RC 衰减分量的叠加。其中，直流分量数值不确定，会随着环境光强的变化而变化；RC 衰

减分量表现为短时间内电平下降 0.2V，然后逐渐恢复至 0。

同理，在人离开探头的探测范围后，热释电传感探头输出端会有一个大约为 0.1V 左右的压升，然

后电平仍然会基本类似于 RC 衰减，缓慢回到原来的电压水平。

根据热释电传感探头的工作原理，我一共设计了两版热传感电路，其工作原理都是基于检测传感

器是否有电平变化来判断是否有人进出传感探头检测范围，并且最终的输出量都为一个二值数字

量。

我设计的第一版热传感电路原理图如图7所示。

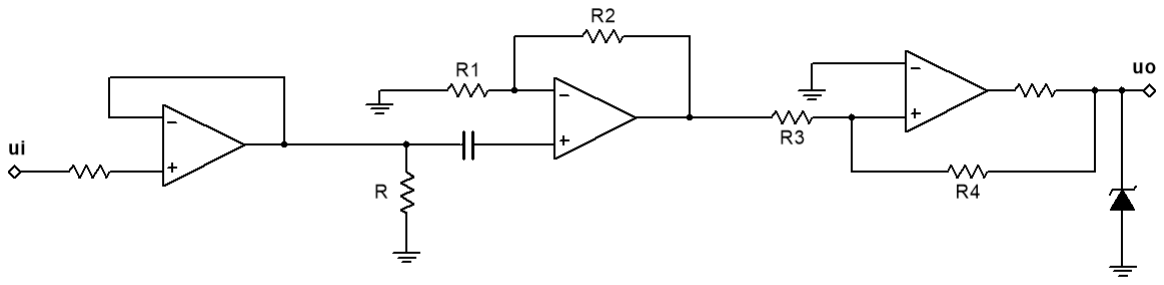
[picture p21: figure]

图 7: 热释电测量电路第一版

如图所示，输入信号首先经过一个跟随器以实现阻抗变换，增大输入内阻，然后输入信号通过一

个一阶高通电路隔离直流分量，并适当放大变化电压幅值，最后通过滞回比较器来输出一个符合

数字电压要求的电平。其中，如果输出由高电平变至低电平，则代表有人进入检测范围，如果由

低电平变为高电平，则代表有人离开检测范围。

但是这一版工作电路在我实际测量时发现主要存在以下几个问题：

- 所需要的电源种类过多。原因在于电路中的运放在第一版设计中，需要正负 12V 供电。但是

由于我的电路最初为 12V 直流电池供电，所以并不能直接提供这两种电平。这导致电路中需

要具备相对比较复杂的正负电源电路才能解决问题。

- 电路出现误检测现象。有人缓慢离开检测范围时，热释电传感探头输出电压会出现幅值过小

的问题。这时，如果仅仅是增大电压放大倍数，则会因为有效信号和环境噪声幅值相近，输

出电压会多次翻转，最终电平的高低与人是否离开检测范围没有确定关系。

为了解决上述问题，我设计的第二版热释电传感电路如图8所示。

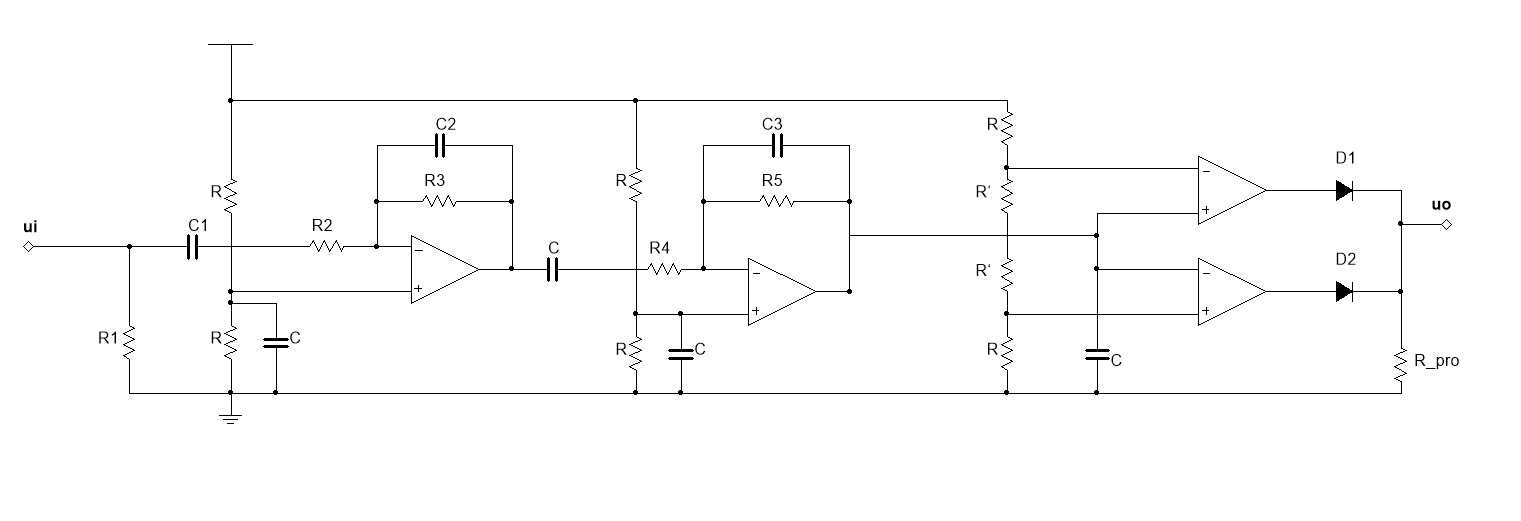
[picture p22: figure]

图 8: 热释电传感电路第二版

其中，R1 和 C1 构成第一级高通滤波器，负责过滤直流电平，然后输入信号经过第一级高通滤波

电路进一步滤波，并通过 R2，R3 实现电压放大。之后输入信号通过 C 进一步隔离直流风量，并

通过第二级电路进行输出值幅值调整并进一步滤波。随后，输入信号通过一个双限电压比较器进

行电压比较，在有人进出电路能输出一个高电平。

针对第一版电路中存在的问题，我做了如下几点改进：

- 针对第一个问题，第二版电路中的运放都用 5V 和 0V 供电。并且将电路中各个基准电位用

R 和 C 控制为 2.5v。这样电路中就仅仅需要 0V 和 5V 的电源供电。

- 针对第二个问题，我将最后一级滞回比较器改为一个窗口比较器。这样做可以让电路在无人

进出时输出一个低电平，只有在有人进出检测范围时输出一个高电平。虽然此时，仍然存在

人缓慢离开而导致的电路误触现象，但是此时可以通过在后一级 MCU 内增加一个最小缓冲

时间（即认为在输出电压变化后一定时间内，电压的再次变化为环境噪声所致，可以忽略）来

抑制环境噪声。

这样做的缺点在于，电路输出值电平高低与是否有人在检测范围内并没有明确的逻辑对应关

系，而仅仅能判断是否有人进出检测范围。但这样的改进结果已经优于第一版电路中，输出

电平的高低和是否检测到人之间逻辑对应关系可能因环境噪声而错误的结果。

窗口比较器的输入电压为：

uin =

R5
R4

R3
R2
∆ui | (6)

其中，R5

R4 负责进行交流信号的放大部分，而 R3
R2 负责调整（放大或者减小）输入窗口比较器的输

入电压以满足窗口比较器的电压比较要求。

窗口比较器的两个阈值输入电压为：

ul =

R
2(R+R′)

uh =

R+2R

′
2(R+R′)

(7)

5. 升压斩波电路

在我们学习过的电路中，并没有一种模拟电路能实现 DC/DC 升压的效果。在经过调查后，我发

现，通常使用的升压电路为升压斩波电路 (BOOST)。由于身边没有合适的电感，所以对于这一部

分电路我选择直接购买现有的模块，而不是自己从头搭建。所以，尽管其作为模拟电路，其详细

原理在此并不详细叙述，仅仅假设其不仅能够有效升压，还拥有足够的功率输出能力。

### 4.2 数字电路模块

1. 18650 12V 直流电源

电路的电源来源于 18650 12V 锂电池。其电池容量为 2600mAH，瞬时最大输出功率为 60W，经

过大致估算，从输出功率和电池容量上来说，应该是满足我的项目需要的。

2. 12V DC 风扇

我购买的为 AFB0812M 12V 直流风扇。当供电电平为 12V 时，其最大所需电流（根据规格说明）

大致在 0.18A 左右。由于风扇存在机械转动，所以风扇应该为电路功率消耗的最主要的来源。经

过估算，在使用 18650 锂电池的情况下，风扇大致可转动 14 小时，所以从功率消耗上是满足要

求的。

3. L298N 电机驱动模块

为了实现风扇转速可调，我使用了一个 L298N 电机驱动模块来实现 pwm 波控制风扇转速的功能。

其原理是通过 H 桥电路，将主控板输出的幅值为 5V 的 pwm 波调制为幅值为 12V 的 pwm 波并

输出给风扇，对于直流风扇而言，在输入的 pwm 波占空比不同时，相当于在风扇两端加不同电平

的直流电压，从而实现风扇转速可调的功能。

4. Arduino Mega 控制板

我使用的主控板为 Arduino Mega2560，其外设包括：

- 数字量输入输出口，其电平变化范围为 0-5V
- 模拟量输入口，电平检测范围为 0-5V
- pwm 输出口，可以输出幅值为 0-5V，占空比不同的 pwm 波
- 中断输入口，可以用于检测热释电传感器输出值变化
- 5 个串行输入输出口，可以用于实现蓝牙调试和连接
- IIC 总线，可以用于与 LCD 显示屏之间的数据通信

Arduino Mega 上的外设是满足我的项目需求的。

5. LCD 显示屏

我使用的显示屏为 LCD1602 显示屏。其使用方式比较简单。它通过 IIC 总线和主控板之间进行数

据传输。主控板通过 IIC 总线来写入 LCD1602 上一块 RAM 内存，然后由显示屏根据其上 RAM

的内容来显示对应信息。

在本项目中，我使用 LCD 显示屏来实现来显示实时温度测量结果和是否有人进出热释电传感器

检测范围的判断结果。

6. 蓝牙模块

蓝牙模块原理十分简单，其基本原理基于串口通信，在进行波特率设置和通信协议设置后，可以

将其直接视为普通串口通信来使用。

而对应的 APP 可以使用上个暑季小学期所掌握的 QT5 开发框架来实现移动端的程序编写。

## 5 模拟电路仿真结果

5.1 5V 稳压电路

仿真电路如图9所示：

图 9: 5V 稳压仿真电路

这里我使用了一个 10kΩ 的滑动变阻器来调节电压关系。最终，在 R2 = 2.9kΩ 时，电路的输出波

形如图10所示：

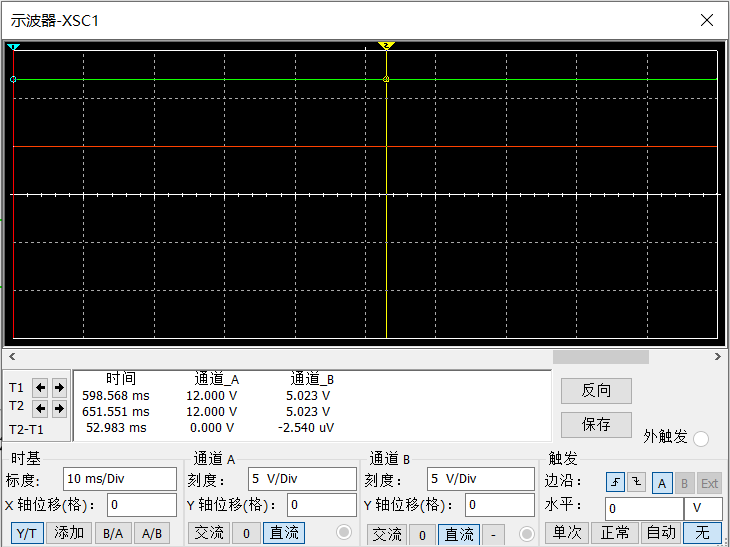
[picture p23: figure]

图 10: 5V 稳压电路输出波形

可以看出，在输入电压基本不变时，输出电压比较稳定。

该模块的传输特性曲线如图11所示：

图 11: 5V 稳压仿真电路传输特性曲线

从图中可见，只有当输入电压大于 6.45V 时，输出电压才能稳定在 5V 不变。

在输入电压为 12V 时，电路的输出电压随后一级电路输入电阻的变化曲线如图12所示。

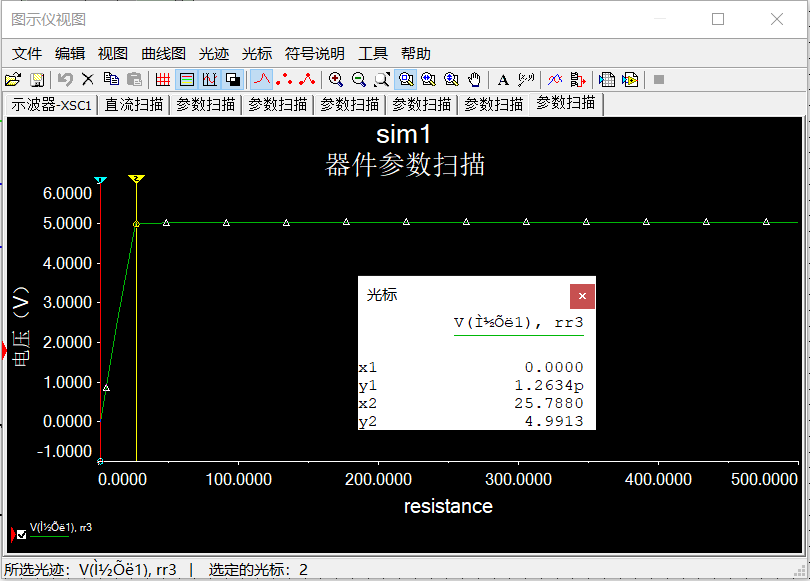
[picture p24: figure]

图 12: 5V 输出电压受后一级输入电阻的影响

可以看出，只有当后一级电路的等效输入电阻大于 25Ω 时，输出电压才能稳定在 5V。电路带载能

力较强。

### 5.2 正负电源电路

正负电源仿真电路如图13所示：


图 13: 正负电源电路

当 R2 = 1.65kΩ, R4 = 0.9kΩ 时，电路的正负电源输出如图14,15所示：

图 14: 正电源输出波形

图 15: 负电源输出波形

此时，正电源 V+ ≈ 10.9V ，负电源 V− ≈ −11.6V 。已经满足了后续运放的电压放大需求。

此时，电路的传输特性曲线如图16所示：


图 16: 电路传输特性曲线

从传输特性曲线中可以看出，要想让电路正常工作，需要保证前一级电路，即升压斩波电路输出电

压大于 25V。

而后一级电路的等效输入电阻对于输出电压的影响曲线如图17,18所示：

图 17: 后一级电路输入电阻对于正电源影响

图 18: 后一级电路输入电阻对于负电源影响

可以看出，为获得期望的输出电压，正电源需要保证后一级电路输入电阻大于 41kΩ ，负电源需要

保证输入电阻大于 11.9kΩ。这说明电路带载能力较差。在实际搭建过程中，可以考虑用由功放构成的

跟随器作为缓冲级电路以增强电路带载能力。

### 5.3 温度测量电路

温度测量电路的仿真电路如图19所示：


图 19: 温度测量仿真电路

在这里，我使用了一个 1k 的电阻和一个可滑动的，阻值为 400Ω 的电阻串联模拟铂电阻 PT1000。

每当该滑动变阻器阻值上升百分之一，就可以近似的看成环境温度上升 1 摄氏度。这意味着该滑动变

阻器的百分比可以直接被近似看做环境温度。

当 R2 滑动变阻器的百分比为 27% （模拟环境温度 27 摄氏度），电桥两端的输出电压如图20所示：

图 20: 电桥输出电压

测量结果与近似计算式 (3) 的计算结果基本一致。

最终输出电压如图21所示。

图 21: 电路输出电压

此时，在实际搭建电路，调整电路参数时，可以通过 Rf R+ 来调节输出电压的变化范围，以满足主控

板 Arduino Mega 上 DAC 芯片的电平转换范围。

电路输出电压随温度（R2 阻值）的变化特性如图22所示：

图 22: 输出电压随温度变化的特性曲线

可以看出，此时电路有足够好的线性性质，可以用于简单的温度测量。

需要注意的是，在仿真中我使用的是 LM324 通用型运放，但是在实际搭接电路时，我使用的是

OPA277 精密运放来进一步提升电路精度。

### 5.4 热释电测量电路

由于我最终使用的，是我改版以后的第二版热释电测量电路，所以在这里只展示第二版电路的仿真

结果。

第二版热释电测量电路的仿真电路如图23所示：


图 23: 热释电测量仿真电路

在仿真时，我使用了一个 RC 电路加一个单刀双掷开关来模拟传感器的输入电压变化过程。在无

人进出检测范围时，输入电平基本维持在一个直流电压稳定不改变。当有人进入检测范围时，电平先有

大约 200mV 的压降，然后逐渐恢复至原电压水平；当有人离开检测范围时，电平先有大约 200mV 的

压升，然后逐渐恢复为原电压水平。

（模拟）传感器输入波形如图24,25所示:


图 24: 传感器输入波形-有人进入

图 25: 传感器输入波形-有人离开

在两种不同的情况下，第一级电路的输出波形分别如图26,27所示：

图 26: 第一级输出波形-有人进入

图 27: 第一级输出波形-有人离开

可以看出，此时第一级电路输出的最高电平为 3.5V，输出的最低电平为-0.5V。可以被第二级电路

有效识别。

此时第二级电路输出波形如图28,29所示：


图 28: 第二级输出波形-有人进入

图 29: 第二级输出波形-有人离开

此时，第二级电路经过一定比例的电平缩小以后，其输出的最高电平为 3.5V，输出的最低电平为

1.98V。可以被后一级窗口比较器识别。

最后一级电路的输出波形如图30,31所示：

图 30: 最终输出波形-有人进入

图 31: 最终输出波形-有人离开

可以看出，在有人进出检测范围时，最后一级电路都可以正常输出一个矩形波。

对于电路的响应恢复速度，测量结果如图32,33所示：


图 32: 电路响应时间-下降

图 33: 电路响应时间-上升

可见，不论是人进入检测范围还是人离开检测范围，系统的响应恢复时间都在 20mS 以内。这说明

在现实世界中，电路是可以及时为下一次人的动作变化做好准备的。

至此，所有由自己搭建的模拟电路模块仿真完成。

## 6 电路搭建与实测结果

### 6.1 模拟电路模块

1. 5V 电源模块：

我最终搭建的 5V 电源模块如图34所示：

图 34: 5V 电源模块

经过调整，其最终的输出电平波形如图所示：


图 35: 5V 电源模块输出波形

最终输出电压为 4.94V，近似为 5V，已经满足下一级电路的电平需求，同时电压上下波动幅度大

约只有 0.1-0.2V，电路稳压性能较好。

2. 正负电源模块

我最终搭建的正负电源模块如图36所示：


图 36: 正负电源模块

在输入电压大于 26V 时，输出电压波形如图所示：


图 37: 正电压输出波形


图 38: 负电压输出波形

最终输出的正电压为 12.02V，负电压为-12.06V，同时，电压稳定性能较好。但是如果直接在后一

级加入电阻，则发现输出电平会降低，这说明电路的带载能力较弱。在引入功放构成的跟随器做

缓冲级后，问题得到了解决。

3. 温度测量模块

我搭建的温度测量模块如图39所示：

图 39: 温度测量模块

其中，电压跟随器我仍然使用了 LM324，但是运算电路部分使用了一个 OPA277 精密运放来提升

电路运算精度。同时，我引入了多个可调变阻器来快速调节电路参数。

最终，测得环境温度（用手持红外成像仪测量）和输出电压之间的关系如下表所示：

温度 T/

◦C | 输出电压 Vout/V
26 | 0.261
29 | 0.279
31 | 0.299

表 1: 温度和输出电压之间的关系

由于测试条件所限，只能测得这 3 组比较有代表性的输入。根据验算可知，这三点基本在一条直

线上，由于数据量较少，所以在此并不做数据拟合。

对于 Arduino Mega 主控板的 ADC 芯片，通过调整前一级电压放大倍数，环境温度可以通过公

式8近似计算：

temp = (readin)/2 | (8)

其中，read_in 为 ADC 芯片所读取值（变化范围为 0-1023）。虽然这样一来温度测量精度只有 0.5

摄氏度，但是对于相对简单的风扇调节应用来说已经满足其基本需求。

4. 热释电传感模块

我搭建的热释电传感模块如图40,41所示：

图 40: 自制热释电传感探头

图 41: 热释电传感实验电路

其中，图40为我自己用硬纸板和绝缘胶带制作的带有菲涅尔滤镜的热释电探头，图41为我搭建的

热释电实验电路。

最终，在有人进出检测范围（实际测量大约为 20cm）时，电路输出波形如图42所示：


图 42: 最终输出波形

此时电路的输出电压能满足下一级数字电路的检测要求，但是电路的恢复时间大约为 200ms，长

于仿真时测量的时间。这是因为现实世界中传感器工作状态和仿真时不同而导致的。实际传感器

输出电压恢复时间比仿真时时间要长，所以最终电路输出波形的实际恢复时间也要长于仿真时间。

5. 升压斩波电路

我使用的升压斩波电路模块如图43所示：


图 43: BOOST 电路模块

其输出电平波形如图44所示：


图 44: BOOST 电路模块输出波形

其输出电平为 27.03V，满足后级电路要求，且经过测试发现其带载能力较强。

### 6.2 数字电路模块

1. Arduino Mega 开发板

我使用的 Mega 板如图45所示：

图 45: Arduino Mega 开发板

其主控代码和连线如下：

1 | /∗ main . ino ∗/
2 | #include <s t d l i b . h>
3 | #include <Wire . h>
4 | #include <LiquidCrystal_I2C . h>

5

6 | // set the LCD address to 0x20 for a 16 chars and 2 l i n e display
7 | LiquidCrystal_I2C lcd (0x20 , 1 6 , 2 ) ;

8

9 | //pin
10 | int sensor = A5 ;
11 | int peopel_pin = 2;
12 | int fan_pin = 3;

13

14 | f l o a t temprature ;
15 | f l o a t tmp;
16 | bool has_people = f a l s e ;
17 | unsigned long last_time = 0 ;

18

19 | void setup ()
20 | {
21 | attachInterrupt (0 , toggle_people ,RISING) ;
22 | pinMode( fan_pin ,OUTPUT) ;

23

24 | lcd . i n i t ( ) ; | // i n i t i a l i z e the lcd
25 | lcd . backlight ( ) ;

26

27 | lcd .home ( ) ;
28 | lcd . clear ( ) ;

29

30 | lcd . print (” i n i t complete ” ) ;
31 | delay (2000);
32 | lcd . clear ( ) ;
33 | }

34

35 | void loop ()
36 | {
37 | tmp = analogRead ( sensor ) ; | //read temprature
38 | temprature = tmp/2;

39

40 | lcd . clear ( ) ; | //begin show
41 | lcd . setCursor ( 0 , 0 ) ;
42 | lcd . print (”temp : ” ) ;
43 | lcd . print ( temprature ) ;
44 | lcd . setCursor ( 0 , 1 ) ;

45

46 | i f ( has_people )
47 | {
48 | lcd . print (” has people ” ) ;
49 | i f ( temprature > 30)
50 | {
51 | analogWrite ( fan_pin , 2 5 5 ) ; // control fan to max speed
52 | }
53 | e l s e
54 | {
55 | analogWrite ( fan_pin , 1 8 0 ) ; // control fan to lower speed
56 | }
57 | }
58 | e l s e
59 | {
60 | lcd . print (”no people ” ) ;

61

62 | analogWrite ( fan_pin , 0 ) ; | //shutdown fan
63 | }

64

65 | delay (1000);
66 | }

67

68 | void toggle_people () | // i f detect people in or out
69 | {
70 | i f ( m i l l i s ()−last_time> 500) | //here set a minimum time to avoid
71 | { | //mistake , set at 500 ms
72 | has_people = ! has_people ;
73 | }

74

75 | last_time = m i l l i s ( ) ;
76 | }

需要注意的是，我在这里设置了一个 500ms 的防误触时间，也就是说，如果在 500ms 内有多次

人进出检测范围的情况，则主控板只会检测一次。如果为了提升电路检测的实时性，可以适当减

少此处的防误触时间。

2. LCD 显示屏

我使用的 LCD 显示屏如图46所示：

图 46: LCD 显示屏

这是一个只有 2 行，每行 16 个字符的显示屏，仅能初步满足显示需求。

3. L298N 电机驱动模块

我使用的电机驱动模块如图47所示：

图 47: L298N 电机驱动模块

4. 12V 直流风扇

我使用的 12V 直流风扇如图48所示：


图 48: 12V 直流风扇

5. 18650 锂电池

我使用的锂电池如图49所示：

图 49: 18650 锂电池

后来由于时间问题，我并没有如预期一样开发一个蓝牙 APP，所以在此就并不展示我使用的蓝牙

模块了。

以上模块经过测试都没有问题。

### 6.3 综合调试

整体调试电路如图50所示：


图 50: 整体调试电路

最终测试结果良好，所得展示视频一共有两个：人进出感应范围的视频“people_in_out.mp4”，以

及人在范围内不同温度下风扇的转速不同的视频“people_in_temp_rise.mp4”，两个视频现都已经放

在了“./2-experiment” 文件夹下。

（提示，温度和有无人的检测结果可以根据 LCD 显示屏上的结果来进行判断，而对应的风扇转速

变化如果不好肉眼观察，可以通过听风扇转动声响来区分。当风扇转速实在过慢时，风叶转动会有十分

明显的噪声，与正常情况下风扇的无噪声运动十分不同)

## 7 实验中电路出现的问题以及原因分析

这个项目的复杂度，是我在设计之前从未想到的。我在这个过程中，遇到的主要问题主要有如下几

点：

1. 前一级输出电流不足的问题

前一级输出电流不足的问题，在电源模块中体现的尤为明显。在正负电源模块中，当我加入后一

级电路后，我发现前一级电路往往因为输出功率不够（以及后一级输入电阻对前一级电路的影响）

的原因，原先调整好的电压又会发生偏移，需要重新对进行前一级电路的输出电压调整。情况严

重时，甚至无法通过调整的方式使得前一级输出电压恢复到期望电压。

对于这一问题，我通过在前后级电路中间，引入由功放构成的电压跟随器解决了问题。这样一来，

一方面功放基本可以满足后一级模拟电路的电流需求，另一方面，对于前一级电路而言，后一级

输入电阻相当于无穷大，降低了对其带载能力的要求。所以带载能力的问题成功得到了解决。

2. 热释电传感器检测范围不足

对于我设计出来的第一版电路，我最终测试所得的比较稳定的检测范围仅仅为 5-8cm，这远远低

于我项目的使用要求。又由于其还存在其他问题（见“4 基本电路模块电路原理/4.1 模拟电路模

块/4. 热释电测量电路”），所以我设计了第二版实验电路，但即使是这样，最终稳定的检测距离也

只有 20cm 左右，超出这一范围则会有漏检测和误检测的现象。这样的检测距离，与市面上的被

动式热释电传感器 7m 左右的检测范围相差过大。

经过我调查得知，现在热释电传感器的主流电路实现方案为使用 BIS0001 运算芯片，基本电路如

图51所示。


图 51: 经典热释电传感电路

BIS0001 运算芯片内部由多个运放以及一定的数字逻辑电路构成，其电路复杂度比个人的实验电

路要复杂得多，所以能实现更为精确的检测精度和更加广阔的检测范围也就并不奇怪了。

3. PT1000 体积过小，给升温和温度测量带来了很大的麻烦。

在测量 PT1000 上温度和输出电压之间的关系，以验证电路设计没有问题的过程中，我发现，实

验室的 PT1000 电阻为裸电阻，其体积不足半个指甲盖大，这给其上的升温，降温，以及温度检测

带来了很大的不便。为了测量其上温度，并且尽量减少对电路的干扰，我从社团处借了一个手持

热成像仪，通过主动式红外传感来获取 PT1000 上的近似温度；而为了对它进行升温和降温，由

于缺乏实验条件，我只能用手捂和吹气的方式来改变 PT1000 表面温度，这也给实验带来了很大

的不便。最终我仅仅获得几组比较有代表性的数据，没能够获得电路输出电平随环境温度的近似

变化曲线。

4. 电源种类过多

这是我本次电路设计中的硬伤。在我最初设计的电路中，由于要使用到正负 12V 来给运放供电，

而整体电路的电源仅为一个 12V 的锂电池，所以需要使用一个正负电源模块。而为了保证正负电

源模块正常工作，又需要保证其输入电压大于 26V，这就意味着电路中又需要引入一个 DC/DC

升压模块。同时，由于部分电路和传感器（比如主控板 Arduino Mega 和 L298N 电机驱动模块）

需要工作在 5V 电压下，所以电源管理电路中还需要一个 12V 转 5V 的电压模块。仅仅在电源管

理电路中，电路就需要用到 3 个模拟电路模块：升压斩波电路，正负电源电路以及 5V 稳压电路

模块。

这样的设计一方面会像上文所述，带来输出功率不足的问题；另一方面，功放和三端稳压器的引

入会明显提升电路功耗，而这并不是一款便携式电子产品设计所希望看到的。

所以说，在第二版热释电传感电路的设计中，我就充分考虑到了这个问题。一方面，我将所需要

的电源总数减少为 1 个，也就是说仅仅需要一个 5V 的电压；同时，为了配合这个 5V 的电压，使

得电路能够正常工作，我将所有运放的正极参考电压全部设置为 2.5V，通过这样的方式让电路近

似的以 2.5V 作为中间值，在 2.5V 上下进行电压波动。不论是仿真还是实测都证明了这样的电路

设计是可行的。

但是比较遗憾的是，由于时间问题，我没能够将温度传感电路也同样改为只需要 5V 电压的单电

源电路。而从原理上来说，由于温度传感电路中，常用的电压值都在 0-5V 之间，所以温度传感电

路是存在被改为单电源电路的可能的。

这个问题同时也让我理解到并行工程这一思想的重要性，不仅在设计电源时要考虑到各个电路模

块的需求，也需要在设计电路模块时，减少所需要电源种类并降低对于电源质量的要求。这样一

来，通过电路模块之间的相互配合来降低电路复杂度，提升电路工作性能。

同时，由于时间关系，整个项目比较遗憾的包括：

1. 没有减少电源种类，使得现在的电源管理模块数量过多
2. 超出课程所学范围的升压斩波电路并没有自己搭建，并研究一下其工作原理和实际工作特性。
3. 由于 Arduino Mega ADC 芯片的精度，最终只能实现精度为 0.5◦C 的温度测量
4. Multisim 没能够使用支电路的方式，进行一次整体电路仿真
5. 没能够在调试完整体电路以后，用 Altium Designer 画一块双层 PCB 板来简化电路连线
6. 没有足够的时间来实现自己原本想要编写的手机端 APP
7. 所使用的显示屏过于简单，缺少进一步的人机互动

## 8 项目的改进方向

项目下一步的改进方向包括有：

### 8.1 模拟电路部分

1. 对于热释电传感器，可以尝试使用 BIS0001 芯片进行更高层次的模拟电路设计，以此来进一步提

升热释电传感的检测精度

2. 对于温度检测电路，在电桥电路处使用恒流源电路来将 PT1000 阻值变化直接转变为电信号，从

而省去近似估算的过程，提高电路检测的精确度。

同时，考虑使用在淘宝上有售卖的更大一些的 PT1000 探头而不是 PT1000 裸电阻。这样一来，一

方面是方便测试其 PT1000 表面温度，另一方面也方便将其和电路隔离开来，单独对其进行加热

降温等操作，从而获得更大的温度变化范围，能够更加准确的验证输出电压和 PT1000 表面温度

之间的关系。

除此以外，将双电源改为单电源供电也应该是下一步改进的方向之一。

最后，可以考虑使用差分放大芯片代替精密运放以实现电路的差分放大。但是我并不确定这样做

能够提升检测精度，只能说可以将其仅仅作为一个改进的尝试方向。

3. 对于电源管理电路，一方面，应该尽可能的减少所使用的电源种类，这样一来既可以减少功放管

的使用，又可以降低电路功耗。

### 8.2 数字电路部分

1. 对于主控板，由于在实验过程中，Arduino 上的 ADC 芯片精度不够，导致最终温度的可识别精

度也只有 0.5 摄氏度。为了进一步提升温度检测的准确度除了在模拟电路部分进一步做电路改进

以外，也应该考虑在主控板上外接一个精度更高的 AD 采集模块（比如 16 位 AD 采集模块），或

者更换 Arduino 控制板为 STMF407 开发板（前者使用的是一块 10 位 AD 模块，后者使用的是

一块 12 位逐次逼近型 AD 转换模块）。

2. 更换 LCD 显示屏。可以更换其为更大的 LCD 显示屏甚至是触摸屏，增强与用户之间的互动性。
3. 开发蓝牙移动端 APP，让用户可以通过手机直接操控风扇

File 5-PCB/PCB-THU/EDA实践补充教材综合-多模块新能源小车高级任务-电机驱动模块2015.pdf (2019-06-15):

# EDA 实践补充教材

# 多模块新能源小车 电机驱动模块 （试用版）

### 清华大学基础工业训练中心

### 虚拟仪器实验室

2015 年

EDA 实践补充教材

Copyright © 2002-2013 清华大学基础工业训练中心虚拟仪器实验室. All rights reserved

目 录

### 六． 整机装配与调试 | 错误!未定义书签。

## ●实习目的

利用多模块新能源小车由学生完成从电路原理仿真验证、印制电路板设 计制造直到元器件检测、焊接、安装、调试的产品设计制造全过程，培养同 学们的工程实践能力。

## 一． 实验平台简介

因材施教的多模块 EDA 实践教学平台多模块新能源小车和比赛平台组 成，多模块新能源小车包括核心控制模块、电源模块、传感模块、驱动模块、 机械传动模块等组成部分，学生既可以将自己设计、制造的模块和标准模块 组合构造系统，也可以团队合作用自制模块构建系统；比赛平台为一套新能 源比赛和测试平台，包括太阳能、磁场能等充电装置和赛道。 学生可选择自己设计、制造的模块现有三个，包括电机驱动模块、太阳 能收集模块和传感模块。
电机驱动模块：

1.1 模块概述

电机驱动模块在整车系统中主要负责小车的前进，后退，拐弯等行驶功能。 电机驱动模块电路原理图如下所示


图 1.1-1 电机驱动模块电路原理图

1.2 模块构成与工作原理

在电机驱动模块电路设计中采用的是 H 桥电路驱动原理。


4 个三极管组成 H 的 4 条垂直腿，而电机就是 H 中的横杠。H 桥式电机 驱动电路包括 4 个三极管和一个电机。要使电机运转，必须导通对角线 上的一对三极管。根据不同三极管对的导通情况，电流可能会从左至右 或从右至左流过电机，从而控制电机的转向。要使电机运转，必须使对 角线上的一对三极管导通。例如，当 Q1 管和 Q4 管导通时，电流就从电 源正极经 Q1 从左至右穿过电机，然后再经 Q4 回到电源负极。按图中电 流箭头所示，该流向的电流将驱动电机顺时针转动。


图 1-1 多功能新能源小车

图 1-2 EDA 实践教学比赛平台

## 二． 设计专用库的导入


1．打开 Multisim11 软件，单击菜单栏上的 Tools/Database/Merge Database 命 令，打开“Database Merge”对话框(如图 2-1 所示)。

图 2-1 “Database Merge”对话框
2．在“Database Merge”对话框的 Target database 区域中，选中“Corporate database”选项，然后单击“Select a Component Database Name”命令。在 新弹出的对话框中，先选择文件类型为“Corporate database(CPComp_S.prj)”， 再选中 THDZGY-EDA 实践专用库“CPCOMP_S.PRJ”，单击“打开(O)”。如图 2-2 所示：

图 2-2“Select a Component Database Name”对话框 3．单击“打开(O)”后会回到“Database Merge”对话框，此时已完成源数


据库与目录数据库的选择，单击“Start”命令后弹出“Resolve Duplicate Component Name”对话框如图 2-3 所示，在此对话框中选择第二项（覆盖方 式）后单击“OK”后选择“Yes”确认

图 2-3 “Resolve Duplicate Component Name”对话框 4．数据加载完成后可以得到图 2-4 所示的报告，说明元件库已成功导入合并， 此时关闭此对话框完成 THDZGY-EDA 实践专用库“CPCOMP_S.PRJ”的导入。

图 2-4 导入报告

## 三． 原理图设计与仿真

选用软件 Multisim 11
1． 电机驱动模块电路仿真测试原理图和元器件清单


图 3-1 EDA 实践高级任务电机驱动模块电路仿真测试原理图

图 3-1 为 EDA 实践高级任务电机驱动模块电路仿真测试原理图，仿真过 程中分别用开关 S1，S2 和 LED101, LED102 模拟仿真电机两条不同的驱动回 路，LED 代替“电动机”。当按照表 1-1 要求调整开关时，1 个 LED 发光， 相当电机通电转动过程。
表 3-1 EDA 实践高级任务电机驱动模块控制时序
EnableA | M1A0 | M1A1 | A0 | A1 | LED
1 | 0 | 0 | 0 | 0 | 停
1 | 0 | 1 | 0 | 1 | LED101 亮(逆)
1 | 1 | 0 | 1 | 0 | LED102 亮(顺)
1 | 1 | 1 | 1 | 1 | 停
0 | ~ | ~ | 0 | 0 | 停

表 3-2、表 3-3、为本次 EDA 实践高级任务示例元器件清单，包括元器 件名、序号、指定原理图库、封装名、指定封装库、引脚标称值、焊盘设计

值、制作印制板时使用钻头直径等，请注意查询使用。

注：电源、地等为虚拟零件，使用 Master Database 的 Sources\POWER_SOURCES 库中的 DC_POWER 和 DGND。

表 3-2 EDA 实践高级任务电机驱动模块元器件清单一

NO | 1 | 2 | 3 | 4 | 5 | 6 | 7
RefDes | Vcc | | LED101-L ED102 | S1-S2 | R101-R11 0 | Q101-Q11 2 | D101-d10 8
Quantity | 2 | n | 2 | 2 | 10 | 12 | 8
| Component | DC_POWER | GROUND | LED | SPST_NO_ SB | 1k | 2SC2001 2SC2655 2SA954 | 1N4245GP
| Database | Master Database | Master Database | Master Database | Master Database | Master Database | Corporat e Database | Corporat e Database
| Group | Sources | Sources | Diodes | Basic | Basic | Transist ors | Diodes
| Family | POWER_SO URCES | POWER_SO URCES | LED | SWITCH | RESISTO R | BJT_NPN | DIODE
| Footprint type | | | | | TH-RES0. 5 | TH-TO-9 2 | TH-DO-35
| Database | | | | | Corporate Database | Corpora te Databas e | Corpora te Databas e
| Group | | | | | THDZGY-V1.1 | THDZGY-V1.1 | THDZGY-V1.1
| 引脚标称值 （mm) | | | | | φ0.55 | 0.38X0. 46 | φ0.55
| 引脚测量值 （mm)
| 焊盘内径设 计值 (mm/mil) | | | | | 0.75/30 | 0.80/32 | 0.75/30
| 焊盘设计值 (mil) | | | | | φ90 | 64X84 | φ90
| 使用钻头直 径（mm) | | | | | φ0.8 | φ0.8 | φ0.8

M u l t i s i m

U l t i b o a r d

表 3-3 EDA 实践高级任务电机驱动模块元器件清单二

NO | 8 | 9
RefDes | U101-U1 02 | J101-J104 EN101
Quantity | 2 | 5
| Component | 74LS00N | HDR1X2(1) HDR1X3(1) HDR1X4(1)
| Database | Corpora te Databas e | Corporate Database
| Group | Analog | Basic
| Family | OPAMP | CONNECTOR S
| Footprint type | TH-DIP1 4 | TH-HDR1X2 TH-HDR1X3 TH-HDR1X4
| Database | Corpora te Databas e | Corporate Database
| Group | THDZGY-V1.1 | THDZGY-V1 .1
| 引脚标称 值（mm) | 0.25X0. 46 | 0.64X0.64
| 引脚测量 值（mm)
| 焊盘内径 设计值 (mm/mil) | 0.72/29 | 1.11/44
| 焊盘设计 值(mil) | 64X84 | φ116
| 使用钻头 直径（mm) | φ0.8 | φ1.0

M u l t i s i m

U l t i b o a r d

2．元器件调用
元器件调用分为两类。一类如电阻、电容在 Master Database 的 Basic/RESISTOR 和 Basic/CAPACTTOR 库中取用，调用元件后需双击元件， 在 value 选项卡中使用 Edit footprint 功能从 Corporate Database 中选取指定的 封装，并手工选择 symbol pins 和 footprint pins 的对应关系； 另一类元件在 选取时从 Corporate Database 中选取，使用默认封装不需修改。 更换电阻封装示例：双击元器件，点击Edit Footprint命令按钮，通过Select From Database 命令选取 Corporate Database 库。在 Corporate Database 库中选 用 TH-RES0.5 封装形式；在 Footprint Pin 区域中选择补充元件引脚对应关系， 使电阻的两个管脚一一对应（同名对应，如 1 对 1、2 对 2…），如图 3-2 所 示。


图 3-2 更换电阻封装图

3．电路仿真

首先修改仿真设置项，单击菜单栏上的 Simulate/interactive Simulation Settings 命令，进入“interactive Simulation Settings”对话框，选中 Maximum time step(TMAX): 选项，并将数值修改为 0.01S,如图 3-3 所示。


图 3-3 “interactive Simulation Settings”对话框 确定如图 3-1 仿真原理图绘制正确并完成仿真设置项修改后，按下 开关后，通过调整 S1、S2 以及 J1 开关的接通位置，观察 LED 点亮情况。 验证了电路的工作原理即：S1 接 Vm，S2 接 GND 且 J1 断开情况下， LED102 点亮。反之，当 S2 接 Vm，S1 接 GND，J1 断开，则 LED101 点亮。 当 S1、S2 同时接 Vm 或者 GND 时，LED 均不亮。当 J1 闭合的情况下，无 论 S1、S2 怎么变化，LED 均不亮。

4．建立 EDA 实践高级任务电机驱动模块电路印制板设计校验原理图


图 3-4 EDA 实践高级任务电机驱动模块电路印制板设计校验原理图 为了利用原理图对 Ultiboard 11 印制板设计软件设计的印制板进行校验， 需建立于印制板设计要求对应的校验用原理图，可以通过修改仿真测试原理 图实现。其中应保证印制板设计所需的所有元件均应采用真实元件，否则无 法传送；电源/信号源类元件和仿真时替代外接传感器的开关均选用虚拟元件 实际需外接，应取用连接器作为印制板上的输入输出端子；将不出现在印制 板上的元件删除；原理图文件名请采用英文；Multisim 向 Ultiboard 传送后应 注意检查是否缺少元件.

## 四． 印制板设计

选用软件 Ultiboard 11：Ultiboard 11 是 Multisim 11 对应的印制板设计软件。 1．建立 THDZGY-EDA 标准模板
完成 EDA 实践高级任务示例电路印制板设计校验原理图的修改和绘制

后，利用 Multisim 传输功能将数据传到 Ultiboard11 中，Ultiboard11 会自动 建立一个项目。
在 Ultiboard11 建立的项目中首先删除原有默认的边框，然后单击菜单栏 上的 File/import/DXF…命令导入 THDZGY_EDA _V2.10.dxf 文件，建立 THDZGY-EDA 标准模板，导入选择如图 4-1 所示，在 Layers 区域选中 Merge import data into existing layer 选项，并选择 Board Outline，在 Units 区域选中 Interpret units in file as 选项，并选择 mm，点击 OK 确定。


图.4-1 DXF Import Settings 对话框


2．设定单位制和格点距离
单击菜单栏上的Options/PCB Properties命令选择Grid & units页，在Units 区域的 Design units:选项选择设置图纸的单位为英制单位 mil。将 Grid 区域的 Visible grid 选项设置为 25，即设置可视格点距离为 25mil； 将 Part grid 选项 设置为 50，即设置零件摆放格点距离为 50mil，如图 4-2 所示。

图.4-2 Grid & units 设置
3．设定线宽和布线间距
在屏幕下方的信息窗中的 Nets 选项卡 Trace width 选项中选择线宽，在 Trace clearance 选项中选择布线间距，请选择线宽 35mil，布线间距 12mil。 如图 4-3 所示

图.4-3 线宽和布线间距设置 1
单击菜单栏上的 Options/PCB Properties 命令选择 Design rules 页，设置 Trace Width 为 35mil，Clearance 区域选项均为 12mil，如图 4-4 所示。


图.4-4 线宽和布线间距设置 2
4．印制板布局设计
参照原理图中的连接关系移动元件形成布局图，保存布局图。

5．自动布线
单击菜单栏上的 Options/PCB Properties 命令选择 Copper Layers 页，将 Layer Pairs：选项设置为 1，即设置使用一对板层布线（双面板）；在 Allow Routing 区域中编辑 Copper Top 层（点击 Properties），将 Routing 选项划掉， 只允许在 Bottom 层布线（单面板）。如图 4-5 所示。


图.4-5 Copper Layers 设置


单击菜单栏上的 Autoroute/Start/Resume Autoroute 命令可以开始自动布 线如图 4-6 所示，注意信息栏中的提示。

图.4-6 自动布线
注意使用菜单栏上的 Edit/Copper Delete/All Copper 命令可以删除所有 布线和导通孔，使用菜单栏上的 Edit/Undo 命令消除上次操作（例如自动布 线结果），使用菜单栏上的 Transfer/Forward Annotate Form File…命令可以 重新调入网络表，如图 4-7 所示。进行 DRC 检查。

图.4-7 传输功能

6．调整布线设计图
完成自动布线后需手工优化布线结果，包括调整线宽、线距、导线走向 等。使印制板更符合工艺要求。最后，在印制板布线铜箔层的空白处添加自 己的学号（文字应镜像处理！）。


参考图例

## 五． 制作

1． 印制板制作; 参照下面的工作流程图，完成印制板的设计与制作。; 热转印机; 图 4-8 热转印法制板工艺流程; 电脑设计 PCB; 将PCB 图形1∶1 打; 印到热转印纸上; 将热转印纸固 定到敷铜板上; 敷铜板下料及表面处理; 热转印; 清洗/涂助焊剂; 蚀刻机; 激光打印机

2．印制板的安装
（1） 元器件检测
全部元器件安装前必须进行测试(见表 4-1 和表 4-2)。
（2） 印制板焊接
其中电阻、电容、二极管、三极管的装配工艺要求如图 4-9 所示，注 意二极管、三极管及电解电容的极性。


（a）三极管 | （b）电解电容 | （c）二极管、电阻
图 4-9 元件安装工艺要求图

表 4-1 EDA 实践电机驱动模块高级任务元件测试要求表

元器件名称 | 测 试 内 容 及 要 求
电阻 | 阻值是否合格
二极管 | 正向导通，反向截至。极性标志是否正确（注：有色环的一边为负极性）
三极管 | 判断极性及类型： 8050、9014(D)为 NPN 型 β值大于 200。

表 4-2 EDA 实践电机驱动模块高级任务材料清单

序 号 | 代 号 | 名 称 | 规格及型号 | 数量 | 检测
1 | R101-R110 | 电阻 | 1K | 10
2 | Q101,Q102 Q107,Q108 | 三极管 | 2SC2001 | 4
3 | Q103,Q104 Q109,Q110 | 三极管 | 2SC2655 | 4
4 | Q105,Q106 Q111,Q112 | 三极管 | 2SA954 | 4
5 | D101-D108 | 二极管 | 1N4245GP | 8
6 | U101,U102 | 集成电路 | 74LS00N | 2
7 | EN101,J103 ,J104 | 插座 | HDR1X2(1) | 3
8 | J102 | 插座 | HDR1X3(1) | 1
9 | J101 | 插座 | HDR1X4(1) | 1

## 课程信息

开课单位 | 清华大学基础工业训练中心
教师姓名 | 韦思健
电子邮件 | wei@mail.tsinghua.edu.cn
电话 | 62781922-1608
参考教材 | 电脑辅助电路设计____Multisim2001 电路实验 与分析测量
作业上传（ftp） | 166.111.198.26 用户名：EDA 密码：EDA

# 工程实践 求实创新 追求卓越

# 清华大学基础工业训练中心 虚拟仪器实验室

地址： 清华大学南门内 500 米路东

E-mail：THVILAB@mail.tsinghua.edu.cn

电话： 62781922

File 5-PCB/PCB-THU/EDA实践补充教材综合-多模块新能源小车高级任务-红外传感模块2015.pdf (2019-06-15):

# EDA 实践补充教材

# 多模块新能源小车 红外传感模块 （试用版）

### 清华大学基础工业训练中心

### 虚拟仪器实验室

2015 年

### 3.1 模块概述

红外模块在整车系统中主要负责循迹，使车能够正确在画有黑线的白色桌子

“路面”上的按我们规定的路线（即黑线“道路”）行驶。其主要循迹方法就是

红外探测法，即利用红外线在不同颜色的物理表面具有不同的反射性质的特点。

红外模块工作电路原理图如下所示：


图 3.1-1 红外模块工作电路原理图

### 3.2 模块构成与工作原理

电路原理图由红外检测和信号处理两个模块构成，如图 3.2-2 所示，在信号

处理模块中运用了运放 LM393P 作为电压比较器，那么什么是电压比较器呢？电

压比较器是对输入信号进行鉴幅与比较的电路，是组成非正弦波发生电路的基本

单元电路，在测量和控制中有着相当广泛的应用。

电压比较器的电压传输特性是输入电压 uI 是模拟信号，而输出电压 uO只有

两种可能的状态，不是高电平 UOH，就是低电平 UOL，用以表示比较的结果。使

uO从 UOH 跃变为 UOL，或者从 UOL跃变为 UOH的输入电压称为阈值电压，或转折

电压，记作 UT。

这里主要用的是电压比较器中的单限比较器，而且是单限比较器中的非过零


比较器，过零比较器和非过零比较器的区别是阈值电压 UT是否等于 0V，所以下

面以单限比较器中的过零比较器为例介绍其工作原理。

过零比较器，其阈值电压 UT=0V，过零比较器及其电压传输特性如图 3.2.-1

所示，集成运放工作在开环状态，其输出电压为+UOM或-UOM。当输入电压 UI<0V

时，UO=+UOM；但 UI>0V 时，UO=-UOM。若想获得 UO 跃变方向相反的电压传输特

性，则因在电路中将反相输入端接地，而在同相输入端接输入电压。

图 3.2.1 过零比较器及其电压传输特性

图 3.2-2 电路原理图构成模块

红外检测主要运用 TCRT5000 红外对管实现，红外反射式对管传感器由 1 个

红外发射管（发射器）和 1 个光电晶体三极管（接收器）构成。红外发射管发出

的红外光在遇到反光性较强的物体（表面为白色或近白色）后被折回，被光电晶

体三极管接收到，引起光电晶体三极管光生电流的增大。将这个转为电压信号，

就可以被信号处理接受并处理，进而实现对反光性差别较大的两种颜色（如黑白

两色）的识别。小车在行驶过程中不断地向地面发射红外光，当红外光遇到白色

地面时发生漫反射，反射光被接收管接收；如果遇到黑线则红外光被吸收，则接

收管接收不到信号。

由于红外反射式传感器属于接近式传感器，其光电晶体三极管光生电流随所

受到的反射光的强度而连续变化，因而会引起其两端电压的连续变化。因此若直

接把这个电压信号供给给处理器，容易产生误读情况，所以如电路原理图所示，

用电位器（R1）产生一个阈值电压，当光电晶体三极管的光生电流超过某一值时，

运放（LM393P）的反相输入端电压高于阈值电压时，运放的输出电压就发生跃

变，输出低电压，该信号就可以被处理器处理。通过对阈值电压的调整，可以调

整传感器的灵敏度和探测距离。

### 3.3 红外模块原理图设计与仿真

1、 红外模块示例电路仿真测试原理图工作原理和元器件清单


图 3.3-1 红外模块示例电路仿真测试原理图

图 3.3-1 为红外模块示例电路仿真测试原理图，仿真过程中用开关 S301

模拟仿真在传感器在线路上（即黑线上），通过 LED1 也可以判断该传感器是

否在线路上，如果在黑线上则灯亮，否则等灭。

表 3.3-1 为红外模块示例元器件清单（包括制版原理图部分的元件清单）。

表 3.3-1 红外模块示例元器件清单

No | 1 | 2 | 3 | 4 | 5 | 6 | 7
RefDes | R302～ R329 | R301 | H301～ H307 | U301～ U304 | LED301 ～ LED307 | S301 | J301
Quantity | 28 | 1 | 7 | 4 | 7 | 1 | 1
| Component | *Ω | 10k | TH-TCRT 5000 | LM393P | LED_red | MUSHR OOM_H EAD | HDR1X9
| Database | Master Databas e | Master Databas e | Corpora te Databas e | Corpora te Databas e | Master Databas e | Master Databas e | Corpora te Databas e
| Group | Basic | Basic | Misc | Analog | Diodes | Electro_ Mechani cal | Basic
| Family | RESISTO R | POTENTI OMETER | SENSER | OPAMP | LED | MOMEN TARY_S WITCHE S | CONNEC TORS
| Footprint type | TH-RES0 .5 | TH-TSR-065 | TH-IRS | TH-DIP8 | / | / | TH-HDR 1X9
| Database | Corpora te Databas e | Corpora te Databas e | Corpora te Databas e | Corpora te Databas e | / | / | Corpora te Databas e
| Group | THDZGY -V1.1 | THDZGY -V1.1 | THDZGY -V1.1 | THDZGY -V1.1 | / | / | THDZGY -V1.1

Multisim

Ultiboard

2、电路仿真

打开 LED301 属性对话框，选中 value 选项卡，将 On Current（Ion）中

的值修改为 0.5mmA，如图 3.3-2 所示。


图 3.3-2 LED 参数修改

验证电路的工作原理：电源接通后，S301 开关是闭合时红外接收管接收

到被折回的红外信号，H301 的 3 输出低电平，LM393P 的 1 脚（或 7 脚）输

出高电平，此时 LED 是灭的；当 S301 开关打开时红外接收管没有接收到被

折回红外信号，光生电流为 0，此时 H301 的 3 脚输出高电平，LM393P 的 1

脚（或 7 脚）输出低电平，此时 LED 是亮的。红外模块的仿真波形图如图 3.3-3

所示。


图 3.3-3 红外模块的仿真波形图

3、建立红外模块示例电路印制板设计校验原理图

为了利用原理图对 Ultiboard11 印制板设计软件设计的印制板进行校验，

需要建立满足印制板设计要求对应的校验原理图。为了满足电路板设计的要

求，该原理图是由 7 个相同的仿真原理图模块构成，实现一块电路板上同时

有 7 个红外模块，红外模块印制板设计校验原理图如图 3.3-4 所示。


图 3.3-4 红外模块印制板设计校验原理图

### 3.4 制版电路板设计

1、边框的导入

本模块与其他模块的边框导入有些区别，特别需要注意，本模块需要进

行两次边框导入过程，第一次导入边框层（如图 3.4-1（a）Merge import data

into existing layer 选择“Board Outline”），资源文件为扩展库中的

“THDZGY-EDA-V3.10A.DXF”，第二次导入丝印层（如图 3.4-1（b）Merge

import data into existing layer 选择“Silkscreen Top”），资源文件为

扩展库中的“THDZGY-EDA-V3.10B.DXF”，如果图 3.4-1 所示。导入完成后最

终边框样式如图 3.4-2 所示。


（a）导入边框 | （b）导入丝印

图 3.4-1 边框导入


图 3.4-2 最终边框样式

2、布局注意事项

本模块设计成双面板，布局过程中必须把 H301～H307 分别放在图 3.4-2

中的 7 个小竖框中，而且元件必须放在 Bottom 层，从左到右按顺序摆放。

将 J301 摆放在大的横框中，且元件必须在 Top 层。LED301～LED307 摆放在

对应的 H301～H307 的上侧，且元件必须在 Top 层，R301 也必须放在 Top 层，

其他元件可以自由布局。

3、布线注意事项

布线过程中需要注意的是只能进行单面焊接，所以必须将所有的焊接点

通过过孔的方式连接到焊接面的焊盘上，如 LED301 元件在 Top 层，则焊接

面在 Bottom 层，所以需要将连接焊盘的导线必须在 Bottom 层上连接焊盘上，

不能在 Top 层直接连接到焊盘上，如果无法直接在 Bottom 层上连接到焊盘

上，则必须通过过孔的方式转到 Bottom 层，然后再将导线连接到焊盘上，

焊接面的导线连接方法如图 3.4-3 所示，（a）是正确的连接方法，（b）是错

误的连接方法。


（a）正确连接方法 | （b）错误连接方法

图 3.4-3 焊接面的导线连接方法

建议过孔尺寸设计要求如图 3.4-4 所示，焊盘直径 60mil，孔径 35mil。

图 3.4-4 过孔尺寸设计要求

4、敷铜要求及步骤

敷铜要求：要求对 PCB 的 Top 层对地（地的网络标号一般默认为 0）敷

铜，敷铜的安全间距建议为 25mil。

敷铜步骤：

1）、点击 Ultiboard 设计窗口中左侧 Design Toolbox 窗口的 Layers 选

项卡，然后双击 Copper Top 将当前工作层设置为 Top 层；

2）、点击菜单“Place→Copper Area”命令；

3）、在 PCB 板框内画出一个闭合区域；

4）、双击敷铜，在弹出的属性对话框中选中 Copper Area 选项卡，在页

面中勾选“Connected to net”，然后在列表框中选择地网络标号（一般默

认为 0），再勾选 Thermal Reliefs 中的“Vias”，最后点击“Apply”按钮，

如图 3.4-5 所示。


图 3.4-5 敷铜属性设置

5）、在弹出的敷铜属性对话框中选中 Position 选项卡，将 Position 中

的 Layer 选择为“Copper Top”，如图 3.4-6 所示。


图 3.4-6 敷铜属性设置

6）、在弹出的敷铜属性对话框中选中 General 选项卡，将 Autoroute

settings 中的选项选择为“Trace can be moved”，将 Clearance 中的 To trace

值设置为 25mil（此处需要注意 Units 中的单位是否为 mil）,最后点击“Ok”

按钮，如图 3.4-7 所示。


图 3.4-7 敷铜属性设置

5、转印建议及注意事项

1）、转印纸的打印：Top 层在打印转印图时必须镜像打印（打印属性窗

中将“Print reflection”勾选上），Top 层打印设置如图 3.4-8 所示，Bottom

层则正常打印即可。


图 3.4-8 Top 层打印设置

2）、印制板转印：印制板转印建议先转印 Top 层， 然后找出三个距离较

远的过孔或焊盘先打孔，然后用大头针穿过这些孔和 Bottom 层转印纸的相

应过孔或焊盘，对好位后固定转印纸，放入转印机转印 Bottom 层。

### 3.5 PCB 板钻孔建议

转印好 PCB 板腐蚀好后，对 PCB 板钻孔时，对焊盘的钻孔建议从焊接面下

钻，过孔建议 Top 层朝上钻孔。

钻孔尺寸要求：1）、TCRT5000：焊盘 1.0mm、两侧固定孔 2.5mm、右下角固

定孔 1.2mm

2）、微调电位器（R301）：1.0mm

3）、插座（J301）：1.0mm

4）、其他：0.8mm

### 3.6 PCB 板的焊接建议

焊接之前先检查 PCB 板是否有短路断路的地方，用刻刀处理好短路的地方，

断路的地方用电阻腿连接好，然后用电阻腿焊接所有的过孔，然后对不同的面进

行从低到高的顺序焊接好所有元器件。

### 3.7 模块调试

1）、上电之前先用万用表的蜂鸣档检查 J301 的 1 脚和 2 脚是否存在电源正

负极短路的情况，然后仔细检查焊接过程中有没有造成其他焊点的短路，如果有

请先排除错误。

2）、接通 5V 电源，将红外传感器离黑线或白色桌面（或白纸）一定高度（1～

5mm）查对应的 LED 灯是否能够正常亮灭（在黑线上 LED 灯亮，在白色物体上

LED 灯灭），如果显示正常则表示电路正常。如果没有正常显示则先微调 R301，

然后再测试，如果问题还没有解决或只是部分传感器存在问题，则仔细检查存在

问题的那路电路是否存在焊接问题或者缺焊漏焊等情况，逐一排查问题。

### 3.8 PCB 板参考图

PCB 板参考图如图 3.8-1（a）、3.8-1（b）、3.8-1（c）、3.8-1（d）所示，分别

是 Top 层 PCB、Bottom 层 PCB、完整 PCB 和 3D 模型图。


3.8-1（a） Top 层 PCB


3.8-1（b） Bottom 层 PCB


3.8-1（c） 完整 PCB


3.8-1（d） 3D 模型图

## 课程信息

开课单位 | 清华大学基础工业训练中心
教师姓名 | 韦思健
电子邮件 | wei@mail.tsinghua.edu.cn
电话 | 62781922-1608
参考教材 | 电脑辅助电路设计____Multisim2001 电路实验与分析 测量
作业上传（ftp） | 166.111.198.26 用户名：EDA 密码：EDA

# 工程实践 求实创新 追求卓越

# 清华大学基础工业训练中心 虚拟仪器实验室

地址： 清华大学南门内 500 米路东

E-mail：THVILAB@mail.tsinghua.edu.cn

电话： 62781922

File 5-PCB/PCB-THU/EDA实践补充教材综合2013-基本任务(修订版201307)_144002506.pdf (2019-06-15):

# EDA 实践补充教材

# 基本任务

### 清华大学基础工业训练中心

### 虚拟仪器实验室

2013 年

EDA 实践补充教材

Copyright © 2002-2013 清华大学基础工业训练中心虚拟仪器实验室. All rights reserved

目录

EDA 实践补充教材 | ~ 1 ~

## 一．EDA 简介

EDA 技术(电子设计自动化-Electronic Design Automation)是电子信息技术

发展的杰出成果,它的发展与应用引发了一场工业设计和制造领域的革命。给企

业带来了巨大经济效益。EDA 技术是以计算硬件和系统软件为基本工作平台,

继承和借鉴了前人在电路、图论与拓扑逻辑和优化理论等多学科的最新科技的

成果，它旨在协助电子设计工程师开发新的电子系统与电路、IC 以及 PCB 产

品时，利用计算机进行设计、分析、仿真、制造等工作，最大限度地降低成本、

节省时间以及提高可靠性。因此 EDA 技术已成为理工科专业学生必备技能之

一。

EDA 技术可以简单划分板级和芯片级，芯片级 EDA 的设计对象为

FPGA/CPLD 或定制芯片，板级 EDA 技术的设计对象为常见的印制电路板。板

级 EDA 技术的学习一般以软件为基础讲授印刷电路板的计算机辅助设计，而对

于板级 EDA 技术全程训练，限于学时和设备，仅有部分专业课程设计有所涉及，

未能面向全体理工科专业学生，需要加以解决。

目前市场上有很多著名的 EDA 软件，包括 ORCAD/PSPICE、P-CAD、PADS、

PROTEL等。在EDA实践课中选用了美国国家仪器公司的系列EDA软件Circuit

Design Suite，包括 Multisim 电路仿真软件和 Ultiboard 印制板设计软件。使用

Multisim 电路仿真软件进行电路原理图的设计、绘制和仿真，可以很方便地利

~ 2 ~ | EDA 实践补充教材


Copyright © 2003-2013 清华大学基础工业训练中心虚拟仪器实验室. All rights reserved

用其虚拟仪表或分析功能判断电路的正确性， Ultiboard 印制板设计软件则可以

很好地与 Multisim 串联使用完成印制板设计。在此基础上可以进一步利用印制

板快速制作系统完成板级 EDA 的全程训练。

Multisim 安装了 Analog Devices、 National Semiconductor、NXP、ON

Semiconductor 和 Texas Instruments 等领先半导体生产商提供的包含多达 22,000

个组件的数据库。 用户可从完整的组件列表中进行选择，包括各种最新的放大

器、二极管、晶体管、切换模式电源和其他用于快速设计和评估模拟和数字电

路的组件。

Multisim 最突出的特点之一是用户界面友好，尤其是多种可放置到设计电

路中的虚拟仪表很有特色。这些虚拟仪表主要包括示波器、万用表、瓦特表、

函数发生器、波特图图示仪、失真度分析仪、频谱分析仪、逻辑分析仪和网络

分析仪等 22 种直观测量仪器，从而使电路仿真分析操作更符合电子工程技术人

员的实验工作习惯。实际上，Multisim 模块是将虚拟仪表的形式与 SPICE 中的

不同仿真分析内容有机结合，如电路中某个节点接“示波器”，就是告诉程序要

对该点处信号进行瞬态分析，接“万用表”就是进行直流工作点分析，接“函

数发生器”就是设置一个 SPICE 源，接“波特图图示仪”就是进行交流小信号

分析，接“频谱分析仪”就是进行快速傅立叶分析。

Multisim 提供了齐全的分析功能，包括直流工作点分析、交流分析、瞬态

分析、傅里叶分析、噪声分析、失真分析、直流扫描分析、灵敏度分析、参数

扫描分析、温度扫描分析、零极点分析、传递函数分析、最坏情况分析、蒙特

卡罗分析、批处理分析、用户自定义分析、射频电路特性分析等 20 种行业标准

的 SPICE 分析。

Ultiboard 布局环境与 Multisim 完全集成，因此用户可将电路快速转换成

PCB 原型。 同时该环境针对快速原型设计进行了优化，可导出和导入 Gerber

和 DXF 等行业标准格式。

## 二．设计专用库的导入

1．打开 Multisim11 软件，单击菜单栏上的 Tools/Database/Merge Database 命令，

打开“Database Merge”对话框(如图 2-1 所示)。


图 2-1 “Database Merge”对话框

2．在“Database Merge”对话框的 Target database 区域中，选中“Corporate

database”选项，然后单击“Select a Component Database Name”命令。在新弹

出的对话框中，先选择文件类型为“Corporate database(CPComp_S.prj)”，再选

中 THDZGY-EDA 实践专用库“CPCOMP_S.PRJ”，单击“打开(O)”。如图 2-2 所示：


图 2-2“Select a Component Database Name”对话框

3．单击“打开(O)”后会回到“Database Merge”对话框，此时已完成源数据

库与目录数据库的选择，单击“Start”命令后弹出“Resolve Duplicate Component

Name”对话框如图 2-3 所示，在此对话框中选择第二项（覆盖方式）后单击“OK”

后选择“Yes”确认


图 2-3 “Resolve Duplicate Component Name”对话框

4．等待一会可以所到图 2-4 所示的报告，说明元件库已成功导入合并，此时关

闭此对话框完成 THDZGY-EDA 实践专用库“CPCOMP_S.PRJ”的导入。

图 2-4 导入报告

## 三．EDA 实践基本任务示例（Multisim11 部分）


图 3-1 所示 EDA 实践示例电路是一个文氏电桥振荡电路，它在运算放大器

的输出端 6 产生频率为 f=1/2*pi*R*C(约为 1061Hz、周期约为 0.9425ms)的正弦

波。为了向 Ultiboard 印制板设计软件传送数据，在绘制仿真原理图时应该注意

这样几点，所有零件均应采用真实元件否则无法传送，电源/信号源类零件均为

虚拟零件，需用连接器作为印制板上的输入输出端子，有些 Multisim 的电路元

器件的封装在 Ultiboard 的数据库中没有或没有配置，需要预先自建或在

Multisim 中手工加入元器件的封装，Multisim 向 Ultiboard 传送后应注意检查是

否缺少零件；Multisim 的文件名请采用英文而不是中文。

本电路的零件清单详见表 3-1 所示，电阻（R1、R2、R3、R4、R5）、电容

（C1、C2）七个真实零件在 Master Database 的 Basic/RESISTOR 和

Basic/CAPACTTOR 库中取用，调用元件后需双击元件，在 value 选项卡中使用

Edit footprint 功能选择指定的封装，并手工选择 symbol pins 和 footprint pins 的

对应关系（同名对应，如 1 对 1、2 对 2…）；741 运算放大器（U1）、1N4148

二极管（D1、D2）和连接器（J1、J2、J3）六个真实零件在 Corporate Database

库中调用，不需更改封装；电源、地等为虚拟零件，使用 Master Database 的

Sources\POWER_SOURCES 库中的 DC_POWER 和 GROUND，不需向 Ultiboard

传送封装信息。

表 3-1 EDA 实践基本任务示例元器件清单

NO | 1 | 2 | 3 | 4 | 5 | 6
RefDes | C1,C2 | R1,R2,R3, R5 | R4 | D1,D2 | J,J1,J3 | U1
Quantity | 2 | 4 | 1 | 2 | 3 | 1
M u l t i s i m | Component | 10nF | 15.0KΩ | 27.0KΩ | 1N4148 | HDR1×2 | 741
| Database | Master Database | Master Database | Master Database | Corporate Database | Corporate Database | Corporate Database
| Group | Basic | Basic | Basic | Diodes | Basic | Analog
| Family | CAPACITOR | RESISTOR | RESISTOR | DIODE | CONNECTOR S | OPAMP
| Footprint type | TH-CAP3 | TH-RES0.5 | TH-RES0.5 | TH-DO-35 | TH-MKDS1X 2 | TH-DIP8
| Database | Corporate Database | Corporate Database | Corporate Database | Corporate Database | Corporate Database | Corporate Database
| Group | THDZGY-V1 .1 | THDZGY-V1 .1 | THDZGY-V1 .1 | THDZGY-V1 .1 | THDZGY-V1 .1 | THDZGY-V1 .1
| 引脚标称 值（mm) | φ0.5 | φ0.55 | φ0.55 | φ0.55 | 0.65X0.65 | 0.25x0.46
| 引脚测量 值（mm)
| 焊盘内径 设计值 (mm/mil) | 0.70/28 | 0.75/30 | 0.75/30 | 0.75/30 | 1.11/44 | 0.72/28
| 焊盘设计 值(mil) | φ84 | φ90 | φ90 | φ90 | φ116 | 64*84

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
按图 3-1 绘制完成仿真原理图后，双击 XSC1 示波器开启示波器面板，令

Channel A的Scale栏位保持为5V/Div，令Timebase的Scale栏位保持为2ms/Div，

按 开关即可观察振荡器输出如图 3-2 所示，待振荡稳定后可以调整

Timebase 的 Scale 栏位观察正弦波周期是否与设计相同。


图.3-2 EDA 实践课基本任务示例测量图

## 四. EDA 实践课基本任务示例（Ultiboard11 部分）

1．建立 THDZGY-EDA 标准模板

完成电路原理图的设计、绘制和仿真后，利用 Multisim 传输功能将数据传

到 Ultiboard11 中，Ultiboard11 会自动建立一个项目。注意传送目录应使用

Ultiboard 的工作目录。

在 Ultiboard11 建立的项目中首先删除原有默认的边框，然后单击菜单栏上

的 File/import/DXF…命令导入 THDZGY_EDA2013_V1.10.dxf 文件，建立

THDZGY-EDA 标准模板，导入选择如图 4-1 所示，在 Layers 区域选中 Merge

import data into existing layer 选项，并选择 Board Outline，在 Units 区域选中

Interpret units in file as 选项，并选择 mm，点击 OK 确定。


图.4-1 DXF Import Settings 对话框

2．设定单位制和格点

单击菜单栏上的 Options/PCB Properties 命令选择 Grid & units 页，在 Units

区域的 Design units:选项选择设置图纸的单位为英制单位 mil。将 Grid 区域的

Visible grid 选项设置为 25，即设置可视格点距离为 25mil； 将 Part grid 选项设

置为 50，即设置零件摆放格点距离为 50mil，如图 4-2 所示。


图.4-2 Grid & units 设置

3．设定线宽和避让距离

在屏幕下方的信息窗中的 Nets 选项卡 Trace width 选项中选择线宽，在

Trace clearance 选项中选择避让距离，请选择线宽 35mil，避让距离 12mil。如

图 4-3 所示


图.4-3 线宽和避让距离设置 1

单击菜单栏上的Options/PCB Properties命令选择Design rules页，设置Trace

Width 为 35mil，Clearance 区域选项均为 12mil，如图 4-4 所示。

图.4-4 线宽和避让距离设置 2

4．印制板布局设计

参照原理图中的连接关系移动元件形成布局图，注意保存布局图。

5．自动布线

单击菜单栏上的Options/PCB Properties命令选择Copper Layers页，将Layer

Pairs：选项设置为 1，即设置使用一对板层布线（双面板）；在 Allow Routing

区域中编辑 Copper Top 层（点击 Properties），将 Routing 选项划掉，只允许在

Bottom 层布线（单面板）。如图 4-5 所示。


图.4-5 Copper Layers 设置

单击菜单栏上的 Autoroute/Start/Resume Autoroute 命令可以开始自动布线

如图 4-6 所示，注意信息栏中的提示。完成自动布线后需手工优化布线结果，

包括调整线宽、线距等。


图.4-6 自动布线

注意使用菜单栏上的 Edit/Copper Delete/All Copper 命令可以删除所有布

线和导通孔，使用菜单栏上的 Edit/Undo 命令消除上次操作（例如自动布线结

果），使用菜单栏上的命令 Transfer/Forward Annotate Form File…可以重新调

入网络表。


图.4-7 传输功能

## 五. 作业要求

EDA 实践课的课程内容包括五部分，第一部分是课堂授课，由教师讲授

EDA 实践的相关内容包括 EDA 知识点、设计流程、软件介绍、基本任务要求

和原理、高级任务要求和原理等；第二部分是课下任务，其中包括学生自学软

件使用；第三部分是上机实验，由学生完成实验电路的原理图绘制、仿真和印

制板布局、布线的全过程；第四部分是制板，学生制作自己设计的电路板；第

五部分是完成焊接、安装、调试等全部制作步骤。

1、基本任务作业要求：利用 Multisim 正确完成示例电路原理图的绘制、仿真，

并传送到 Ultiboard 中完成单面印制板图设计，形成没有 DRC 错误的印制板图，

应在印制板布线铜箔层的空白处添加自己的学号（文字需镜像！）。

2、作业评判标准：电路原理图是否可以正确完成设计功能，电路是否可以传送

到 Ultiboard 完成印制板图设计，印制板图设计是否完整、正确、合理等。

注：评判标准由清华大学基础工业训练中心根据实际情况掌握。

3、作业上交：上机后请将 EDA 实践课作业结果按实习时间(如 0826-0908 或周

一下午)、实习教室（1--3）上载至作业 ftp（166.111.198.26）的 WORK 目录下

的相应子目录。（ftp 用户名 EDA、密码 EDA）

4、上传时须在本机建立个子目录，目录名为本人学号，子目录内包括*.ms11、

*.ewnet、*.ewprj 文件，再将整个目录上传。

## 课程信息

开课单位 | 清华大学基础工业训练中心
教师姓名 | 韦思健
电子邮件 | wei@mail.tsinghua.edu.cn
电话 | 62781922-1608
参考教材 | 电脑辅助电路设计____Multisim2001 电路实验与分析测 量
作业上传（ftp） | 166.111.198.26 用户名：EDA 密码：EDA


# 工程实践

# 求实创新

# 追求卓越

# 清华大学基础工业训练中心 虚拟仪器实验室

地址： 清华大学南门内 500 米路东

E-mail：THVILAB@mail.tsinghua.edu.cn

电话： 62781922

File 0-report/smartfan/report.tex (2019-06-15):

\documentclass{article}
 
\usepackage[margin=1in]{geometry}
\usepackage[strict]{changepage}
\usepackage{float}
\usepackage{fancyhdr}
\usepackage{mhchem}
\usepackage{siunitx}
\usepackage{wrapfig, booktabs}
\usepackage{enumitem}
\usepackage{ctex}
\usepackage{graphicx}
\usepackage{amsmath}
\usepackage{amssymb}
\usepackage{subfigure}
\usepackage{multirow}
\usepackage{multicol}
\usepackage{wrapfig}
\usepackage{indentfirst}
\usepackage[utf8]{inputenc}
\usepackage{geometry}
\usepackage{setspace}   %set space between lines
\usepackage{graphicx} %insert figure 
\usepackage{float} %设置图片浮动位置的宏包
\usepackage{subfigure} %插入多图时用子图显示的宏包
\usepackage{listings}   %插入代码的宏包
\usepackage{xcolor} % to define color 
\usepackage{verbatim}   %for comment 
\usepackage[breaklinks,colorlinks,linkcolor=black,citecolor=black,urlcolor=black]{hyperref} %for bookmark 

\setlength{\parindent}{2em}

\definecolor{mygray}{rgb}{0.5,0.5,0.5}  %totally used in code display
\definecolor{mygreen}{rgb}{0,0.6,0}

\lstset{                %代码显示格式设置
    numbers=left,                                   
    % where to put the line-numbers; possible values are (none, left, right)
    numberstyle=  \color{mygray}, 
    % the style that is used for the line-numbers
    keywordstyle= \color{ blue!70},
    basicstyle=\footnotesize,        
    % the size of the fonts that are used for the code
    commentstyle=\color{mygreen},    
    % comment style
    frame=single,	                   
    % adds a frame around the code, you can use frame=shadowboxs
    % with a rulesepcolor= \color{ red!20!green!20!blue!20} ,
    escapeinside=``, % 英文分号中可写入中文
    xleftmargin=4em,xrightmargin=2em, aboveskip=1em,
    framexleftmargin=2em
} 

\begin{document}

\begin{spacing}{1.5}

    %title  page 
    \thispagestyle{empty}
    \begin{center}
~\\[6cm]\rule{\linewidth}{0.5mm} \\[6mm]
{\Large 综合论文  \\  \textbf{{\LARGE 智能风扇}}  \\[6mm]}
\rule{\linewidth}{0.5mm} \\[2cm]
{\Large 姓 名: 吕光冉}\\[.3cm]
{\Large 班 级:   自73 }\\[.3cm]
{\Large 学 号:  2017011574}\\[.3cm]
{\Large 日 期：\today }\\[.3cm]
    \end{center}

    \clearpage
    \phantom{s}

    %if need to make table of contents in pdf, below command is okay
\tableofcontents
\newpage

    \subsection{摘要}

    本文介绍了一个智能风扇系统的设计与实现。本设计以Arduino Mega为主控板，利用基于PT1000的灵敏
    温度测量电路感知环境温度，利用基于热释电传感探头RE200B的人体感知电路感知人是否在检测范围内出现，
    利用这两个方面的环境信息来自动调整风扇转速。同时，为了实现风扇的可携带性，本设计在电源管理模块中，
    使用了5V电压稳压可调节模块，正负电源模块和DC/DC升压斩波电路等模块来配合12V锂电池来给电路提供电源。

    \textbf{关键词} ：智能风扇；小型电子系统设计；模拟电路；数字电路

\section{引言}

   我所选择的第二个综合论文题目为智能风扇系统的设计与制作。
    
   在炎炎夏日，一个好的可携带风扇对人们就变得十分重要。在我自己使用风扇的过程中，我发现
   市面上所售卖的风扇主要存在以下两个问题：一方面，如果忘记关闭风扇电源，即使是在人已经离开房间
   以后，它也不能自动关闭以节省电池电量，另一方面，大多数风扇都不具备测温功能，只能通过用户手动根据体感温度
   调节风扇转速。

    所以说，我想要自己设计并实现这样一款智能风扇：一，它首先要体积较小，使用电池供电，具有可携带性；二，
    它要能够感知人体，在人离开风扇的检测距离以后，自动关闭风扇；三，它应该能够根据环境温度，智能调节风扇
    转速；四，它最好能实现比较好的用户互动，有显示屏和蓝牙APP等方式来接收用户指令。

\section{设计目标}

\begin{enumerate}
    \item 使用电池供电，具有便携性
    \item 能进行人体检测，在人离开检测范围后，关闭风扇
    \item 能根据环境温度，智能调节风扇转速
    \item 有显示屏显示当前工作状态
    \item 能通过蓝牙进行连接，与用户手机APP进行连接后，由用户调节其在不同温度下的转速
\end{enumerate}

\section{实现方式}

整个电子系统的实现框图如图\ref{fig:design_total}所示：

\begin{figure}[H]
    \centering
    
    \caption{整体电路实现框图}
    \label{fig:design_total}
\end{figure}

在这里，我将整个电子系统分为下列模块：主控板模块，温度传感器模块，热释电传感模块，风扇及其驱动模块，蓝牙模块与对应
的APP，电源电路模块。

其中，热释电传感器是用来实现人体检测的功能，
温度传感器负责检测环境温度，
风扇及其驱动电路负责驱动风扇运转，
蓝牙及APP模块负责实现与用户的蓝牙连接，
主控板Arduino Mega负责实现数字控制逻辑，
即获取热释电传感和温度传感器输出的环境信息，
根据用户蓝牙设置的预定义功能，
自主决定风扇转速。
并且，整个电路的供电问题，都由电源管理模块负责。

其中，根据传感器，主控板，风扇等模块所需要的电源类型，电源管理模块
包括有：

\begin{figure}[H]
    \centering
    
    \caption{电源管理模块设计}
    \label{fig:design_total1}
\end{figure}

而整个项目我的基本调试流程如下：

\begin{figure}[H]
    \centering
    
    \caption{基本调试流程}
    \label{fig:design_flow}
\end{figure}

在下文中，我也将根据这一思路，阐述我的电路的设计过程，仿真结果以及实测结果。

\section{基本电路模块电路原理}

    \subsection{模拟电路模块}

    \begin{enumerate}
        \item 5V稳压电路
        
        5V稳压电路电路原理图：

        \begin{figure}[H]
            \centering
            
            \caption{5V稳压电路原理图}
            \label{fig:design_prin_1}
        \end{figure}
        
        我为了实现5V电压可以进行微调，使用了一个电压可调电路。其中，三端稳压器使用了
        LM317M。在输入电压足够大，公共端ADJ处电流可以近似忽略的条件下，电路输出电压满足关系：

        \begin{equation}
            V_{out} = 1.25(1+\frac{R_2}{R_1}) V
        \end{equation}

        由于使用到了三端稳压器，其脉动系数 S 应该不会太大，可以满足后级电路需求。

        \item 正负电源电路
        
        我设计的正负电源电路原理图如图\ref{fig:design_prin_2}所示：
        \begin{figure}[H]
            \centering
            
            \caption{正负电源电路}
            \label{fig:design_prin_2}
        \end{figure}
        
        在输入电压足够大，并且COMMON端电流可以被近似忽略时，电路输出近似满足下列关系：
        \begin{equation}
            \begin{cases}
                V_{out+} = 5(1+\frac{R_1}{R_2}) V \\
                V_{out-} = -5(1+\frac{R_3}{R_4}) V
            \end{cases}
        \end{equation}

        \item 温度测量电路
        
        温度测量电路原理图如图\ref{fig:design_prin_3}所示：

        \begin{figure}[H]
            \centering
            
            \caption{温度测量电路原理图}
            \label{fig:design_prin_3}
        \end{figure}

        温度测量电路的设计是基于铂电阻（PT1000）的温度特性。铂电阻在不同温度下的阻值不同且数值比较固定，
        在将铂电阻阻值变化转变为电信号后，经过一定的运算电路就可以得到比较精确的温度测量值。

        在电路图中，$R_2$ 为 PT1000 铂电阻，其阻值随温度变化，$R_4$ 为调零电阻，可以调整电路使其在0$^{\circ}C$ 
        时输出为0。
        R1,R2,R3,R4构成电桥电路。电桥电路的两个输出值
        在经过由精密运放构成的跟随器之后，
        进入最后一级电路做差并被放大。
        原理图中C1,C2负责稳定输入电压，消除自激振荡，
        C3负责稳定输出电压，滤去高频噪声。
        
        根据 PT1000 铂电阻的温度特性，在0摄氏度时，PT1000电阻阻值为1000 $\Omega$，其后，每上升1摄氏度，
        其阻值大致上升4 $\Omega$. 则根据R1，R2分压关系，可知在 k 摄氏度时，如果假设$R_1$足够大，则电桥左路的输出电压为：

        \begin{equation}
            V_{+} = \frac{R_2}{R_2 + R_1} V_{CC} = \frac{1000+4k}{R_1 + 1000 + 4k} V_{CC} \approx \frac{1000+4k}{R_1 + 1000 } V_{CC} \label{equ:approx}
        \end{equation}

        此时，若调节电路在0摄氏度时输出为0，则电桥右路输出电压为：
        \begin{equation}
            V_{-} = \frac{R_4}{R_3 + R_4} V_{CC} = \frac{1000}{1000 + R_1 } V_{CC}
        \end{equation}

        因此，在最后一级，当正极输入电阻和输出电阻阻值相等时，有：
        \begin{equation}
            V_{out} = \frac{R_f}{R_{+}} (V_{+} - V_{-}) \approx \frac{R_f}{R_{+}} \cdot \frac{4k}{R_1 + 1000} V_{CC}  
        \end{equation}

        通过最后一级的比例调整，将电压近似的转化为主控板可以直接读取的模拟电压值。

        \item 热释电测量电路
        
        热释电传感电路用于检测指定距离内是否有人存在。其基本测量原理是热释电基于热释电传感探头（三极管）的三端特性。
        热释电传感探头可以将吸收到的红外辐射转化为微弱的电信号，而在热释电探头上加上菲涅尔透镜则可以有效削弱环境干扰信号，
        保留人体热电信号，所以该传感探头可以用于测量是否有人在其探测范围内。

        但是经过测量，我发现，我们使用的被动式热释电传感探头实际上并不完全可靠。当有人进入探头的探测范围（由于项目需要，
        我设定为20cm）后，热释电传感探头输出电平是一个直流分量和近似为RC衰减分量的叠加。其中，直流分量数值不确定，会随着环境光强
        的变化而变化；RC衰减分量表现为短时间内电平下降0.2V，然后逐渐恢复至0。
        
        同理，在人离开探头的探测范围后，热释电传感探头输出端会有一个大约为0.1V左右的压升，
        然后电平仍然会基本类似于RC衰减，缓慢回到原来的电压水平。

        根据热释电传感探头的工作原理，我一共设计了两版热传感电路，其工作原理都是基于检测传感器是否有电平变化来判断
        是否有人进出传感探头检测范围，并且最终的输出量都为一个二值数字量。
        
        我设计的第一版热传感电路原理图如图\ref{fig:design_prin_4}所示。

        \begin{figure}[H]
            \centering
            
            \caption{热释电测量电路第一版}
            \label{fig:design_prin_4}
        \end{figure}

        如图所示，输入信号首先经过一个跟随器以实现阻抗变换，增大输入内阻，
        然后输入信号通过一个一阶高通电路隔离直流分量，并适当放大变化电压幅值，
        最后通过滞回比较器来输出一个符合数字电压要求的电平。
        其中，如果输出由高电平变至低电平，则代表有人进入检测范围，如果由
        低电平变为高电平，则代表有人离开检测范围。

        但是这一版工作电路在我实际测量时发现主要存在以下几个问题：

        \begin{itemize}
            \item 所需要的电源种类过多。原因在于电路中的运放在第一版设计中，需要正负12V供电。
            但是由于我的电路最初为12V直流电池供电，所以并不能直接提供这两种电平。
            这导致电路中需要具备相对比较复杂的正负电源电路才能解决问题。
            
            \item 电路出现误检测现象。
            有人缓慢离开检测范围时，热释电传感探头输出电压会出现幅值过小的问题。这时，如果仅仅是增大电压放大倍数，则会因为
            有效信号和环境噪声幅值相近，输出电压会多次翻转，最终电平的高低与人是否离开检测范围没有确定关系。

        \end{itemize}

        为了解决上述问题，我设计的第二版热释电传感电路如图\ref{fig:design_prin_5}所示。

        \begin{figure}[H]
            \centering
            
            \caption{热释电传感电路第二版}
            \label{fig:design_prin_5}
        \end{figure}

        其中，R1和C1构成第一级高通滤波器，负责过滤直流电平，
        然后输入信号经过第一级高通滤波电路进一步滤波，并通过R2，R3
        实现电压放大。
        之后输入信号通过C进一步隔离直流风量，并通过第二级电路进行输出值幅值调整并进一步滤波。
        随后，输入信号通过一个双限电压比较器进行电压比较，在有人进出电路能输出一个高电平。

        针对第一版电路中存在的问题，我做了如下几点改进：
        \begin{itemize}
            \item 针对第一个问题，第二版电路中的运放都用5V 和 0V 供电。
            并且将电路中各个基准电位用R和C控制为2.5v。这样
            电路中就仅仅需要0V和5V的电源供电。
            
            \item 针对第二个问题，我将最后一级滞回比较器改为一个窗口比较器。这样做可以让电路在无人进出时输出一个
            低电平，只有在有人进出检测范围时输出一个高电平。虽然此时，仍然存在人缓慢离开而导致的电路误触现象，但是此时
            可以通过在后一级 MCU 内增加一个最小缓冲时间（即认为在输出电压变化后一定时间内，电压的再次变化为环境噪声所致，
            可以忽略）来抑制环境噪声。

            这样做的缺点在于，电路输出值电平高低与是否有人在检测范围内并没有明确的逻辑对应关系，而仅仅能判断
            是否有人进出检测范围。但这样的改进结果已经优于第一版电路中，输出电平的高低和是否检测到人之间逻辑
            对应关系可能因环境噪声而错误的结果。

        \end{itemize}

        窗口比较器的输入电压为：

        \begin{equation}
            u_{in} = \frac{R_5}{R_4} \frac{R_3}{R_2} \Delta u_i
        \end{equation}

        其中，$\frac{R_5}{R_4}$ 负责进行交流信号的放大部分，而
        $\frac{R_3}{R_2}$ 负责调整（放大或者减小）输入窗口比较器的输入电压以满足
        窗口比较器的电压比较要求。

        窗口比较器的两个阈值输入电压为：
        \begin{equation}
            \begin{cases}
                u_{l} = \frac{R}{2(R + R')} \\
                u_{h} = \frac{R+2R'}{2(R + R')} 
            \end{cases}
        \end{equation}

        \item 升压斩波电路

        在我们学习过的电路中，并没有一种模拟电路能实现DC/DC升压的效果。在经过调查后，我发现，
        通常使用的升压电路为升压斩波电路(BOOST)。由于身边没有合适的电感，所以对于这一部分电路我
        选择直接购买现有的模块，而不是自己从头搭建。所以，尽管其作为模拟电路，其详细原理在此并不详细叙述，
        仅仅假设其不仅能够有效升压，还拥有足够的功率输出能力。

    \end{enumerate}

    \subsection{数字电路模块}

    \begin{enumerate}
        \item 18650 12V直流电源

        电路的电源来源于18650 12V锂电池。
        其电池容量为2600mAH，瞬时最大输出功率为60W，经过大致估算，从输出功率和电池容量上来说，
        应该是满足我的项目需要的。
        
        \item 12V DC 风扇
        
        %figure 2 

        我购买的为AFB0812M 12V直流风扇。当供电电平为12V时，其最大所需电流（根据规格说明）大致在0.18A左右。
        由于风扇存在机械转动，所以风扇应该为电路功率消耗的最主要的来源。经过估算，在使用18650锂电池的情况下，
        风扇大致可转动14小时，所以从功率消耗上是满足要求的。

        \item L298N 电机驱动模块

        为了实现风扇转速可调，我使用了一个L298N 电机驱动模块来实现 pwm波控制风扇转速的功能。
        其原理是通过H桥电路，将主控板输出的幅值为5V的pwm波调制为幅值为12V的pwm波并输出给风扇，
        对于直流风扇而言，在输入的pwm波占空比不同时，相当于在风扇两端加不同电平的直流电压，
        从而实现风扇转速可调的功能。

        \item Arduino Mega 控制板

        我使用的主控板为Arduino Mega2560，其外设包括：
        \begin{itemize}
            \item 数字量输入输出口，其电平变化范围为0-5V
            \item 模拟量输入口，电平检测范围为0-5V
            \item pwm 输出口，可以输出幅值为0-5V，占空比不同的 pwm 波
            \item 中断输入口，可以用于检测热释电传感器输出值变化
            \item 5个串行输入输出口，可以用于实现蓝牙调试和连接
            \item IIC总线，可以用于与LCD显示屏之间的数据通信
        \end{itemize}

        Arduino Mega 上的外设是满足我的项目需求的。

        \item LCD显示屏

        我使用的显示屏为LCD1602 显示屏。其使用方式比较简单。它通过IIC总线和主控板之间进行数据传输。
        主控板通过IIC总线来写入LCD1602上一块RAM内存，然后由显示屏根据其上RAM的内容来显示对应信息。 
      
        在本项目中，我使用LCD显示屏来实现来显示实时温度测量结果和是否有人进出热释电传感器检测范围的判断结果。

        \item 蓝牙模块

        蓝牙模块原理十分简单，其基本原理基于串口通信，在进行波特率设置和通信协议设置后，可以将其直接视为普通串口通信来
        使用。

        而对应的APP可以使用上个暑季小学期所掌握的QT5开发框架来实现移动端的程序编写。

    \end{enumerate}

\section{模拟电路仿真结果}

    \subsection{5V稳压电路}

    仿真电路如图\ref{fig:sim1}所示：
    \begin{figure}[H]
        \centering
        
        \caption{5V稳压仿真电路}
        \label{fig:sim1}
    \end{figure}
    
    这里我使用了一个$10 k \Omega $ 的滑动变阻器来调节电压关系。最终，在$R_2 = 2.9 k \Omega $ 
    时，电路的输出波形如图\ref{fig:sim1_result1}所示：

    \begin{figure}[H]
        \centering
        
        \caption{5V稳压电路输出波形}
        \label{fig:sim1_result1}
    \end{figure}
    可以看出，在输入电压基本不变时，输出电压比较稳定。

    该模块的传输特性曲线如图\ref{fig:sim1_result2}所示：
    \begin{figure}[H]
        \centering
        
        \caption{5V稳压仿真电路传输特性曲线}
        \label{fig:sim1_result2}
    \end{figure}
    
    从图中可见，只有当输入电压大于6.45V时，输出电压才能稳定在5V不变。

    在输入电压为12V时，电路的输出电压随后一级电路输入电阻的变化曲线如图\ref{fig:sim1_result3}所示。
    \begin{figure}[H]
        \centering
        
        \caption{5V输出电压受后一级输入电阻的影响}
        \label{fig:sim1_result3}
    \end{figure}
    
    可以看出，只有当后一级电路的等效输入电阻大于$25 \Omega $ 时，输出电压才能稳定在5V。 
    电路带载能力较强。

    \subsection{正负电源电路}

    正负电源仿真电路如图\ref{fig:sim2}所示：
    \begin{figure}[H]
        \centering
        
        \caption{正负电源电路}
        \label{fig:sim2}
    \end{figure}

    当$R_2 = 1.65 k\Omega , R_4 = 0.9k \Omega$时，电路的正负电源输出如图\ref{fig:sim2_result1},\ref{fig:sim2_result2}所示：

    \begin{figure}[H]
        \centering
        
        \caption{正电源输出波形}
        \label{fig:sim2_result1}
    \end{figure}
    
    \begin{figure}[H]
        \centering
        
        \caption{负电源输出波形}
        \label{fig:sim2_result2}
    \end{figure}
    
    此时，正电源$ V_+ \approx 10.9V$，负电源$V_- \approx -11.6 V$。已经满足了后续运放的电压放大需求。
    
    此时，电路的传输特性曲线如图\ref{fig:sim2_result3}所示：

    \begin{figure}[H]
        \centering
        
        \caption{电路传输特性曲线}
        \label{fig:sim2_result3}
    \end{figure}
    
    从传输特性曲线中可以看出，要想让电路正常工作，需要保证前一级电路，即升压斩波电路输出电压大于25V。

    而后一级电路的等效输入电阻对于输出电压的影响曲线如图\ref{fig:sim2_result4},\ref{fig:sim2_result5}所示：
    \begin{figure}[H]
        \centering
        
        \caption{后一级电路输入电阻对于正电源影响}
        \label{fig:sim2_result4}
    \end{figure}
    
    \begin{figure}[H]
        \centering
        
        \caption{后一级电路输入电阻对于负电源影响}
        \label{fig:sim2_result5}
    \end{figure}
    
    可以看出，为获得期望的输出电压，正电源需要保证后一级电路输入电阻大于$41k\Omega$ ，负电源需要保证输入电阻大于$11.9k\Omega$。
    这说明电路带载能力较差。在实际搭建过程中，可以考虑用由功放构成的跟随器作为缓冲级电路以增强电路带载能力。

    \subsection{温度测量电路}

    温度测量电路的仿真电路如图\ref{fig:sim3}所示：
    \begin{figure}[H]
        \centering
        
        \caption{温度测量仿真电路}
        \label{fig:sim3}
    \end{figure}
    
    在这里，我使用了一个1k的电阻和一个可滑动的，阻值为400$\Omega$的电阻串联模拟铂电阻PT1000。每当该滑动变阻器阻值上升百分之一，
    就可以近似的看成环境温度上升1摄氏度。这意味着该滑动变阻器的百分比可以直接被近似看做环境温度。

    当$R_2$滑动变阻器的百分比为27\% （模拟环境温度27摄氏度），电桥两端的输出电压如图\ref{fig:sim3_result1}所示：
    \begin{figure}[H]
        \centering
        
        \caption{电桥输出电压}
        \label{fig:sim3_result1}
    \end{figure}

    测量结果与近似计算式 (\ref{equ:approx}) 的计算结果基本一致。
    
    最终输出电压如图\ref{fig:sim3_result2}所示。

    \begin{figure}[H]
        \centering
        
        \caption{电路输出电压}
        \label{fig:sim3_result2}
    \end{figure}

    此时，在实际搭建电路，调整电路参数时，可以通过$\frac{R_f}{R_+}$来调节输出电压的变化范围，
    以满足主控板Arduino Mega 上 DAC芯片的电平转换范围。

    电路输出电压随温度（$R_2$ 阻值）的变化特性如图\ref{fig:sim3_result3}所示：
    
    \begin{figure}[H]
        \centering
        
        \caption{输出电压随温度变化的特性曲线}
        \label{fig:sim3_result3}
    \end{figure}
    
    可以看出，此时电路有足够好的线性性质，可以用于简单的温度测量。
    
    需要注意的是，在仿真中我使用的是LM324通用型运放，但是在实际搭接电路时，我使用的是OPA277精密运放来进一步提升电路精度。

    \subsection{热释电测量电路}

    由于我最终使用的，是我改版以后的第二版热释电测量电路，所以在这里只展示第二版电路的仿真结果。

    第二版热释电测量电路的仿真电路如图\ref{fig:sim4}所示：

    \begin{figure}[H]
        \centering
        
        \caption{热释电测量仿真电路}
        \label{fig:sim4}
    \end{figure}
    
    在仿真时，我使用了一个RC电路加一个单刀双掷开关来模拟传感器的输入电压变化过程。在无人进出检测范围时，输入电平基本维持在一个
    直流电压稳定不改变。当有人进入检测范围时，电平先有大约200mV的压降，然后逐渐恢复至原电压水平；当有人离开检测范围时，
    电平先有大约200mV的压升，然后逐渐恢复为原电压水平。

    （模拟）传感器输入波形如图\ref{fig:sim4_result2},\ref{fig:sim4_result3}所示:

    \begin{figure}[H]
        \centering
        
        \caption{传感器输入波形-有人进入}
        \label{fig:sim4_result2}
    \end{figure}
    
    \begin{figure}[H]
        \centering
        
        \caption{传感器输入波形-有人离开}
        \label{fig:sim4_result3}
    \end{figure}

    在两种不同的情况下，第一级电路的输出波形分别如图\ref{fig:sim4_result5},\ref{fig:sim4_result4}所示：

    \begin{figure}[H]
        \centering
        
        \caption{第一级输出波形-有人进入}
        \label{fig:sim4_result5}
    \end{figure}

    \begin{figure}[H]
        \centering
        
        \caption{第一级输出波形-有人离开}
        \label{fig:sim4_result4}
    \end{figure}

    可以看出，此时第一级电路输出的最高电平为3.5V，输出的最低电平为-0.5V。可以被第二级电路有效识别。

    此时第二级电路输出波形如图\ref{fig:sim4_result9},\ref{fig:sim4_result8}所示：

    \begin{figure}[H]
        \centering
        
        \caption{第二级输出波形-有人进入}
        \label{fig:sim4_result9}
    \end{figure}

    \begin{figure}[H]
        \centering
        
        \caption{第二级输出波形-有人离开}
        \label{fig:sim4_result8}
    \end{figure}

    此时，第二级电路经过一定比例的电平缩小以后，其输出的最高电平为3.5V，输出的最低电平为1.98V。可以被后一级窗口比较器识别。

    最后一级电路的输出波形如图\ref{fig:sim4_result11},\ref{fig:sim4_result10}所示：
  
    \begin{figure}[H]
        \centering
        
        \caption{最终输出波形-有人进入}
        \label{fig:sim4_result11}
    \end{figure}
    
        \begin{figure}[H]
        \centering
        
        \caption{最终输出波形-有人离开}
        \label{fig:sim4_result10}
    \end{figure}

    可以看出，在有人进出检测范围时，最后一级电路都可以正常输出一个矩形波。

    对于电路的响应恢复速度，测量结果如图\ref{fig:sim4_result7},\ref{fig:sim4_result6}所示：

    \begin{figure}[H]
        \centering
        
        \caption{电路响应时间-下降}
        \label{fig:sim4_result7}
    \end{figure}
    
    \begin{figure}[H]
        \centering
        
        \caption{电路响应时间-上升}
        \label{fig:sim4_result6}
    \end{figure}
    
    可见，不论是人进入检测范围还是人离开检测范围，系统的响应恢复时间都在20mS以内。
    这说明在现实世界中，电路是可以及时为下一次人的动作变化做好准备的。

    至此，所有由自己搭建的模拟电路模块仿真完成。

\section{电路搭建与实测结果}

    \subsection{模拟电路模块}
\begin{enumerate}
    \item 5V电源模块：
    
    我最终搭建的5V电源模块如图\ref{fig:module1}所示：
    \begin{figure}[H]
        \centering
        
        \caption{5V电源模块}
        \label{fig:module1}
    \end{figure}
    
    经过调整，其最终的输出电平波形如图所示：

    \begin{figure}[H]
        \centering
        
        \caption{5V电源模块输出波形}
        \label{fig:module1_result1}
    \end{figure}
    
    最终输出电压为4.94V，近似为5V，已经满足下一级电路的电平需求，同时电压上下波动幅度大约只有0.1-0.2V，电路稳压性能较好。

    \item 正负电源模块
    
    我最终搭建的正负电源模块如图\ref{fig:module2}所示：
    \begin{figure}[H]
        \centering
        
        \caption{正负电源模块}
        \label{fig:module2}
    \end{figure}

    在输入电压大于26V时，输出电压波形如图所示：
    \begin{figure}[H]
        \centering
        
        \caption{正电压输出波形}
        \label{fig:module2_result1}
    \end{figure}
    
    \begin{figure}[H]
        \centering
        
        \caption{负电压输出波形}
        \label{fig:module2_result2}
    \end{figure}

    最终输出的正电压为12.02V，负电压为-12.06V，同时，电压稳定性能较好。但是如果直接在后一级加入电阻，则发现输出电平
    会降低，这说明电路的带载能力较弱。在引入功放构成的跟随器做缓冲级后，问题得到了解决。
    
    \item 温度测量模块
    
    我搭建的温度测量模块如图\ref{fig:module3}所示：
    \begin{figure}[H]
        \centering
        
        \caption{温度测量模块}
        \label{fig:module3}
    \end{figure}
    
    其中，电压跟随器我仍然使用了LM324，但是运算电路部分使用了一个OPA277精密运放来提升电路运算精度。同时，我引入了多个可调变阻器
    来快速调节电路参数。

    最终，测得环境温度（用手持红外成像仪测量）和输出电压之间的关系如下表所示：

    \begin{table}[H]
        \centering
        \renewcommand\arraystretch{2}   %used to adjust space between lines 
        \begin{tabular}{cc}
        \toprule
            温度 $T / ^{\circ}C$ &  输出电压 $V_{out} / V$\\
        \midrule
             26 & 0.261 \\ 
             29 & 0.279 \\ 
             31 & 0.299 \\ 
        \bottomrule
        \end{tabular}
        \caption{温度和输出电压之间的关系}
        \label{tab:module3_result}
    \end{table}
    
    由于测试条件所限，只能测得这3组比较有代表性的输入。根据验算可知，这三点基本在一条直线上，由于数据量较少，
    所以在此并不做数据拟合。

    对于Arduino Mega主控板的ADC芯片，通过调整前一级电压放大倍数，
    环境温度可以通过公式\ref{equ:temprature}近似计算：

    \begin{equation}
        temp = (read_in) / 2 \label{equ:temprature} 
    \end{equation}

    其中，read\_in为ADC芯片所读取值（变化范围为0-1023）。虽然这样一来温度测量精度只有0.5摄氏度，
    但是对于相对简单的风扇调节应用来说已经满足其基本需求。

    \item 热释电传感模块

    我搭建的热释电传感模块如图\ref{fig:module4_1},\ref{fig:module4_2}所示：

    \begin{figure}[H]
        \centering
        
        \caption{自制热释电传感探头}
        \label{fig:module4_1}
    \end{figure}
    
    \begin{figure}[H]
        \centering
        
        \caption{热释电传感实验电路}
        \label{fig:module4_2}
    \end{figure}
    
    其中，图\ref{fig:module4_1}为我自己用硬纸板和绝缘胶带制作的带有菲涅尔滤镜的热释电探头，图\ref{fig:module4_2}为我搭建的
    热释电实验电路。

    最终，在有人进出检测范围（实际测量大约为20cm）时，电路输出波形如图\ref{fig:module4_result1}所示：

    \begin{figure}[H]
        \centering
        
        \caption{最终输出波形}
        \label{fig:module4_result1}
    \end{figure}
    
    此时电路的输出电压能满足下一级数字电路的检测要求，但是电路的恢复时间大约为200ms，
    长于仿真时测量的时间。这是因为现实世界中传感器工作状态和仿真时不同而导致的。
    实际传感器输出电压恢复时间比仿真时时间要长，所以最终电路输出波形的实际恢复时间也要长于仿真时间。

    \item 升压斩波电路
    
    我使用的升压斩波电路模块如图\ref{fig:module5}所示：

    \begin{figure}[H]
        \centering
        
        \caption{BOOST电路模块}
        \label{fig:module5}
    \end{figure}
    
    其输出电平波形如图\ref{fig:module5_result1}所示：
    \begin{figure}[H]
        \centering
        
        \caption{BOOST电路模块输出波形}
        \label{fig:module5_result1}
    \end{figure}

    其输出电平为27.03V，满足后级电路要求，且经过测试发现其带载能力较强。

\end{enumerate}

    \subsection{数字电路模块}
\begin{enumerate}

    \item Arduino Mega 开发板
    
    我使用的Mega板如图\ref{fig:module6}所示：
    \begin{figure}[H]
        \centering
        
        \caption{Arduino Mega开发板}
        \label{fig:module6}
    \end{figure}
    
    其主控代码和连线如下：

\begin{lstlisting}
    /* main.ino */
    #include <stdlib.h> 
    #include <Wire.h>
    #include <LiquidCrystal_I2C.h>
    
    // set the LCD address to 0x20 for a 16 chars and 2 line display
    LiquidCrystal_I2C lcd(0x20,16,2);  
    
    //pin 
    int sensor = A5 ;
    int peopel_pin = 2; 
    int fan_pin = 3;
    
    float temprature;
    float tmp; 
    bool has_people = false ; 
    unsigned long last_time = 0 ;
    
    void setup()
    {
      attachInterrupt(0,toggle_people,RISING);
      pinMode(fan_pin,OUTPUT);
    
      lcd.init();                      // initialize the lcd 
      lcd.backlight();
      
      lcd.home();
      lcd.clear();
    
      lcd.print("init complete");
      delay(2000);
      lcd.clear();
    }
    
    void loop()
    {
      tmp = analogRead(sensor) ;    //read temprature 
      temprature = tmp/2;

      lcd.clear();                  //begin show 
      lcd.setCursor(0,0); 
      lcd.print("temp:");
      lcd.print(temprature);
      lcd.setCursor(0,1);

      if(has_people)
      {
        lcd.print("has people"); 
        if(temprature > 30)
        {
          analogWrite(fan_pin,255); //control fan to max speed 
        }
        else
        {
          analogWrite(fan_pin,180); //control fan to lower speed 
        }
      }
      else 
      {
        lcd.print("no people");
    
        analogWrite(fan_pin,0);     //shutdown fan 
      }
    
      delay(1000);
    }
    
    void toggle_people()            //if detect people in or out
    {
      if(millis()-last_time> 500)   //here set a minimum time to avoid
      {                             //mistake , set at 500 ms 
        has_people = !has_people ; 
      }
    
      last_time = millis();
    }        
\end{lstlisting}

    需要注意的是，我在这里设置了一个500ms的防误触时间，也就是说，如果在500ms内有多次人进出检测范围的情况，则
    主控板只会检测一次。如果为了提升电路检测的实时性，可以适当减少此处的防误触时间。

    \item LCD 显示屏
    
    我使用的LCD显示屏如图\ref{fig:module7}所示：
    \begin{figure}[H]
        \centering
        
        \caption{LCD 显示屏}
        \label{fig:module7}
    \end{figure}

    这是一个只有2行，每行16个字符的显示屏，仅能初步满足显示需求。

    \item L298N 电机驱动模块
    
    我使用的电机驱动模块如图\ref{fig:module8}所示：
    \begin{figure}[H]
        \centering
        
        \caption{L298N 电机驱动模块}
        \label{fig:module8}
    \end{figure}

    \item 12V 直流风扇
    
    我使用的12V 直流风扇如图\ref{fig:module9}所示：
    \begin{figure}[H]
        \centering
        
        \caption{12V直流风扇}
        \label{fig:module9}
    \end{figure}

    \item 18650 锂电池
    
    我使用的锂电池如图\ref{fig:module10}所示：
    \begin{figure}[H]
        \centering
        
        \caption{18650 锂电池}
        \label{fig:module10}
    \end{figure}

    后来由于时间问题，我并没有如预期一样开发一个蓝牙APP，所以在此就并不展示我使用的蓝牙模块了。

    以上模块经过测试都没有问题。

\end{enumerate}

    \subsection{综合调试}

    整体调试电路如图\ref{fig:total}所示：

    \begin{figure}[H]
        \centering
        
        \caption{整体调试电路}
        \label{fig:total}
    \end{figure}

    最终测试结果良好，所得展示视频一共有两个：人进出感应范围的视频“people\_in\_out.mp4"，以及
    人在范围内不同温度下风扇的转速不同的视频“people\_in\_temp\_rise.mp4"，两个视频现都已经放在了“./2-experiment"文件夹下。
    
    （提示，温度和有无人的检测结果可以根据LCD显示屏上的结果来进行判断，
    而对应的风扇转速变化如果不好肉眼观察，可以通过听风扇转动声响来区分。
    当风扇转速实在过慢时，风叶转动会有十分明显的噪声，与正常情况下风扇的无噪声运动十分不同)
    
\section{实验中电路出现的问题以及原因分析}    

这个项目的复杂度，是我在设计之前从未想到的。我在这个过程中，遇到的
主要问题主要有如下几点：

\begin{enumerate}
    \item 前一级输出电流不足的问题
    
    前一级输出电流不足的问题，在电源模块中体现的尤为明显。在正负电源模块中，当我加入后一级电路后，我发现
    前一级电路往往因为输出功率不够（以及后一级输入电阻对前一级电路的影响）的原因，原先调整好的电压又会发生偏移，
    需要重新对进行前一级电路的输出电压调整。
    情况严重时，甚至无法通过调整的方式使得前一级输出电压恢复到期望电压。

    对于这一问题，我通过在前后级电路中间，引入由功放构成的电压跟随器解决了问题。这样一来，
    一方面功放基本可以满足后一级模拟电路的电流需求，
    另一方面，对于前一级电路而言，后一级输入电阻相当于无穷大，降低了对其带载能力的要求。
    所以带载能力的问题成功得到了解决。

    \item 热释电传感器检测范围不足
    
    对于我设计出来的第一版电路，我最终测试所得的比较稳定的检测范围仅仅为5-8cm，这远远低于我项目的使用要求。
    又由于其还存在其他问题（见“4 基本电路模块电路原理/4.1 模拟电路模块/4.热释电测量电路”），
    所以我设计了第二版实验电路，但即使是这样，最终稳定的检测距离也只有20cm左右，
    超出这一范围则会有漏检测和误检测的现象。这样的检测距离，与市面上的被动式热释电传感器7m左右
    的检测范围相差过大。

    经过我调查得知，现在热释电传感器的主流电路实现方案为使用BIS0001运算芯片，基本电路如图\ref{fig:review1}所示。
    
    \begin{figure}[H]
        \centering
        
        \caption{经典热释电传感电路}
        \label{fig:review1}
    \end{figure}

    BIS0001运算芯片内部由多个运放以及一定的数字逻辑电路构成，其电路复杂度比个人的实验电路要复杂得多，所以能实现更为精确的检测精度和更加
    广阔的检测范围也就并不奇怪了。
    
    \item PT1000体积过小，给升温和温度测量带来了很大的麻烦。
    
    在测量PT1000上温度和输出电压之间的关系，以验证电路设计没有问题的过程中，我发现，实验室的PT1000电阻为裸电阻，其体积不足半个指甲盖大，
    这给其上的升温，降温，以及温度检测带来了很大的不便。为了测量其上温度，并且尽量减少对电路的干扰，我从社团处借了一个手持热成像仪，通过主动式红外
    传感来获取PT1000上的近似温度；而为了对它进行升温和降温，由于缺乏实验条件，我只能用手捂和吹气的方式来改变PT1000表面温度，这也给实验带来
    了很大的不便。最终我仅仅获得几组比较有代表性的数据，没能够获得电路输出电平随环境温度的近似变化曲线。

    \item 电源种类过多
    
    这是我本次电路设计中的硬伤。在我最初设计的电路中，由于要使用到正负12V来给运放供电，而整体电路的电源仅为一个12V的锂电池，所以需要使用
    一个正负电源模块。而为了保证正负电源模块正常工作，又需要保证其输入电压大于26V，这就意味着电路中又需要引入一个DC/DC升压模块。
    同时，由于部分电路和传感器（比如主控板Arduino Mega 和 L298N电机驱动模块）需要工作在5V电压下，所以电源管理电路中还需要
    一个12V转5V的电压模块。
    仅仅在电源管理电路中，电路就需要用到3个模拟电路模块：升压斩波电路，正负电源电路以及5V稳压电路模块。

    这样的设计一方面会像上文所述，带来输出功率不足的问题；另一方面，功放和三端稳压器的引入会明显提升电路功耗，
    而这并不是一款便携式电子产品设计所希望看到的。

    所以说，在第二版热释电传感电路的设计中，我就充分考虑到了这个问题。一方面，我将所需要的电源总数减少为1个，也就是说仅仅需要一个5V的电压；
    同时，为了配合这个5V的电压，使得电路能够正常工作，我将所有运放的正极参考电压全部设置为2.5V，通过这样的方式让电路近似的以2.5V作为中间值，
    在2.5V上下进行电压波动。不论是仿真还是实测都证明了这样的电路设计是可行的。

    但是比较遗憾的是，由于时间问题，我没能够将温度传感电路也同样改为只需要5V电压的单电源电路。而从原理上来说，由于温度传感电路中，常用的电压值都在
    0-5V之间，所以温度传感电路是存在被改为单电源电路的可能的。

    这个问题同时也让我理解到并行工程这一思想的重要性，不仅在设计电源时要考虑到各个电路模块的需求，
    也需要在设计电路模块时，减少所需要电源种类并降低对于电源质量的要求。
    这样一来，通过电路模块之间的相互配合来降低电路复杂度，提升电路工作性能。

\end{enumerate}

同时，由于时间关系，整个项目比较遗憾的包括：

\begin{enumerate}
    \item 没有减少电源种类，使得现在的电源管理模块数量过多
    \item 超出课程所学范围的升压斩波电路并没有自己搭建，并研究一下其工作原理和实际工作特性。
    \item 由于Arduino Mega ADC芯片的精度，最终只能实现精度为0.5$^{\circ} C$的温度测量
    \item Multisim没能够使用支电路的方式，进行一次整体电路仿真
    \item 没能够在调试完整体电路以后，用Altium Designer画一块双层PCB板来简化电路连线
    \item 没有足够的时间来实现自己原本想要编写的手机端APP
    \item 所使用的显示屏过于简单，缺少进一步的人机互动
\end{enumerate}

\section{项目的改进方向}

项目下一步的改进方向包括有：

    \subsection{模拟电路部分}

    \begin{enumerate}
        \item 对于热释电传感器，可以尝试使用BIS0001芯片进行更高层次的模拟电路设计，以此来进一步提升热释电传感的检测精度
        \item 对于温度检测电路，在电桥电路处使用恒流源电路来将PT1000阻值变化直接转变为电信号，从而省去
        近似估算的过程，提高电路检测的精确度。
        
        同时，考虑使用在淘宝上有售卖的更大一些的PT1000探头而不是PT1000裸电阻。这样一来，一方面是方便测试其PT1000表面温度，
        另一方面也方便将其和电路隔离开来，单独对其进行加热降温等操作，从而获得更大的温度变化范围，
        能够更加准确的验证输出电压和PT1000表面温度之间的关系。

        除此以外，将双电源改为单电源供电也应该是下一步改进的方向之一。

        最后，可以考虑使用差分放大芯片代替精密运放以实现电路的差分放大。但是我并不确定这样做能够提升检测精度，
        只能说可以将其仅仅作为一个改进的尝试方向。

        \item 对于电源管理电路，一方面，应该尽可能的减少所使用的电源种类，这样一来既可以减少功放管的使用，又可以降低
        电路功耗。

    \end{enumerate}

    \subsection{数字电路部分}

    \begin{enumerate}
        \item 对于主控板，由于在实验过程中，Arduino上的ADC芯片精度不够，导致最终温度的可识别精度也只有0.5摄氏度。为了进一步提升温度检测的准确度
        除了在模拟电路部分进一步做电路改进以外，也应该考虑在主控板上外接一个精度更高的AD采集模块（比如16位AD采集模块），或者更换Arduino控制板
        为STMF407开发板（前者使用的是一块10位AD模块，后者使用的是一块12位逐次逼近型AD转换模块）。

        \item 更换LCD显示屏。可以更换其为更大的LCD显示屏甚至是触摸屏，增强与用户之间的互动性。
        
        \item 开发蓝牙移动端APP，让用户可以通过手机直接操控风扇
    
    \end{enumerate}

\end{spacing}
\end{document}

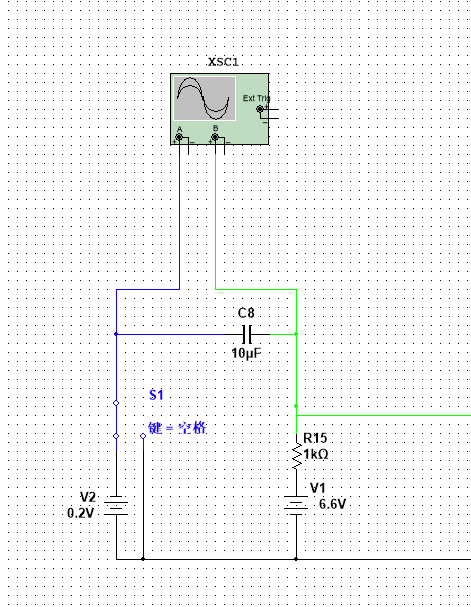
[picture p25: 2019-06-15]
0-report/smartfan/fig/sim/sim4_1.png

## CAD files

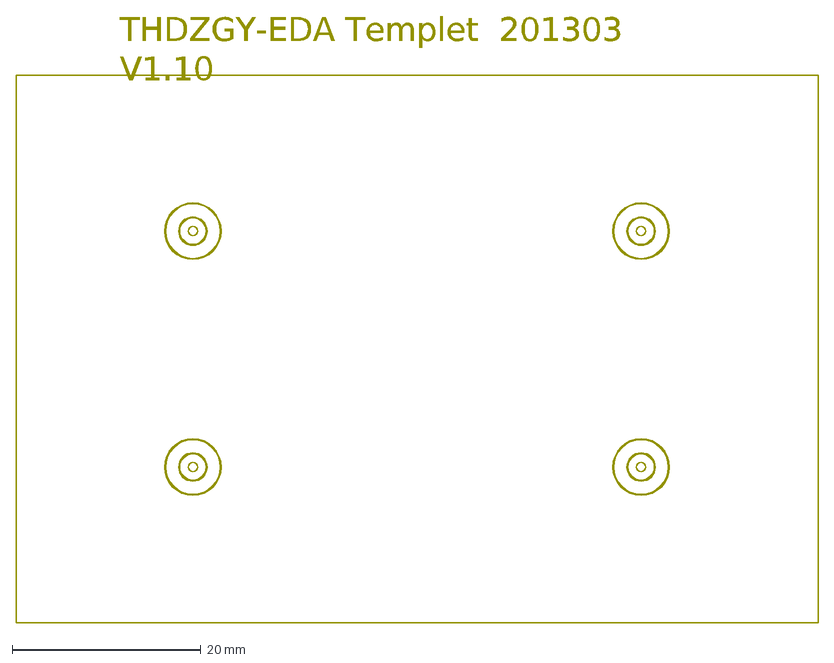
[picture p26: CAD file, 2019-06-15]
5-PCB/PCB-THU/THDZGY-EDA-V1.10.dxf
THDZGY-EDA Templet 201303 V1.10

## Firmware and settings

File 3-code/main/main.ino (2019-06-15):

#include <stdlib.h> 
#include <Wire.h>
#include <LiquidCrystal_I2C.h>

LiquidCrystal_I2C lcd(0x20,16,2);  // set the LCD address to 0x20 for a 16 chars and 2 line display

//pin 
int sensor = A5 ;
int peopel_pin = 2; 
int fan_pin = 3;

float temprature;
float tmp; 
bool has_people = false ; 
unsigned long last_time = 0 ;

void setup()
{
  //pinMode(peopel_pin, INPUT); 
  attachInterrupt(0,toggle_people,RISING);
  pinMode(fan_pin,OUTPUT);

  lcd.init();                      // initialize the lcd 
  lcd.backlight();
  
  lcd.home();
  lcd.clear();

  lcd.print("init complete");
  delay(2000);
  lcd.clear();
  //lcd.clear();
}

void loop()
{
  tmp = analogRead(sensor) ; 
  temprature = tmp/2;
  lcd.clear();
  lcd.setCursor(0,0); 
  lcd.print("temp:");
  lcd.print(temprature);

  lcd.setCursor(0,1);
  if(has_people)
  {
    lcd.print("has people"); 
    if(temprature > 30)
    {
      analogWrite(fan_pin,255);
    }
    else
    {
      analogWrite(fan_pin,180);
    }
  }
  else 
  {
    lcd.print("no people");

    analogWrite(fan_pin,0);
  }

  delay(1000);
}

void toggle_people()
{
  if(millis()-last_time> 500)
  {
    has_people = !has_people ; 
  }

  last_time = millis();
}
